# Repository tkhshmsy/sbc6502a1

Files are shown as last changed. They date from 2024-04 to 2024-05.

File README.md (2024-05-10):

# sbc6502a1
Single Board Computer with 65C02, clone of Apple I

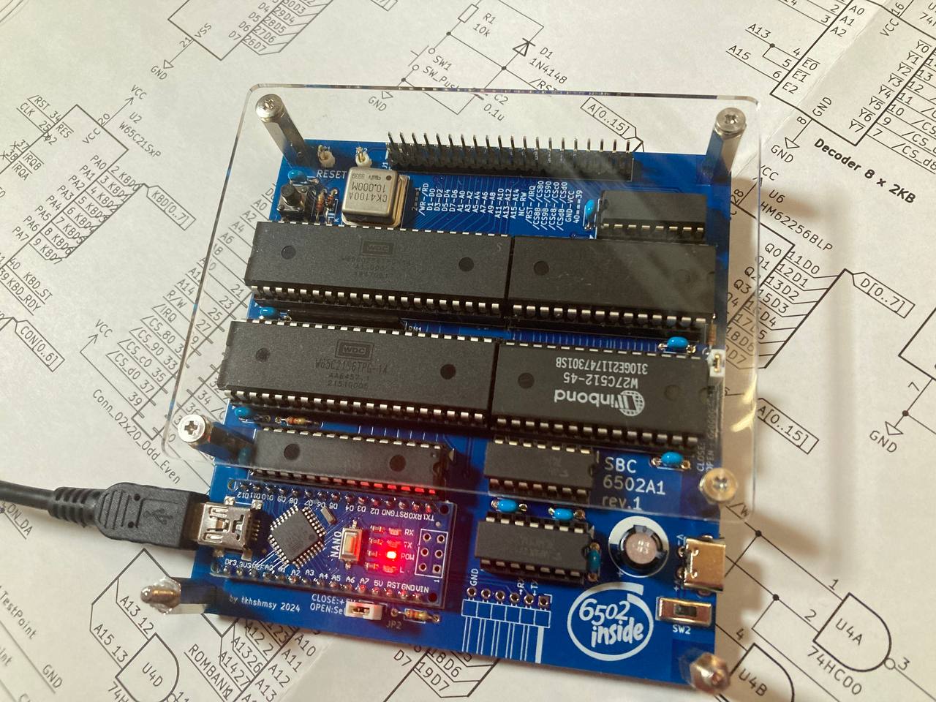
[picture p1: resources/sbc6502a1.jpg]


# Features
* Clone of Apple I.
  * similar but much ** greater ** projects are there.
    * [RC6502](https://github.com/tebl/RC6502-Apple-1-Replica) and [RC6502 Apple 1 SBC](https://github.com/tebl/RC6502-Apple-1-Replica/tree/master/RC6502%20Apple%201%20SBC)
    * [Apple 1 Mini](https://hackaday.io/project/26234/logs)
    * [L-Star](https://github.com/jacgoudsmit/L-Star/)
* Communicate with Host-PC via Serial.
  * using Arduino Nano as [PIA Communicator](https://github.com/jblang/pia_communicator)
* 32KB user RAM is available.
* ROM has 2 bank of each 8KB + 8KB.
  * it is enough for wozmon, Apple1-BASIC, OSI-BASIC and so on.
* Power supply +5VDC from Type-C or via Arduino Nano.

# PCB
## Schematics and Layout
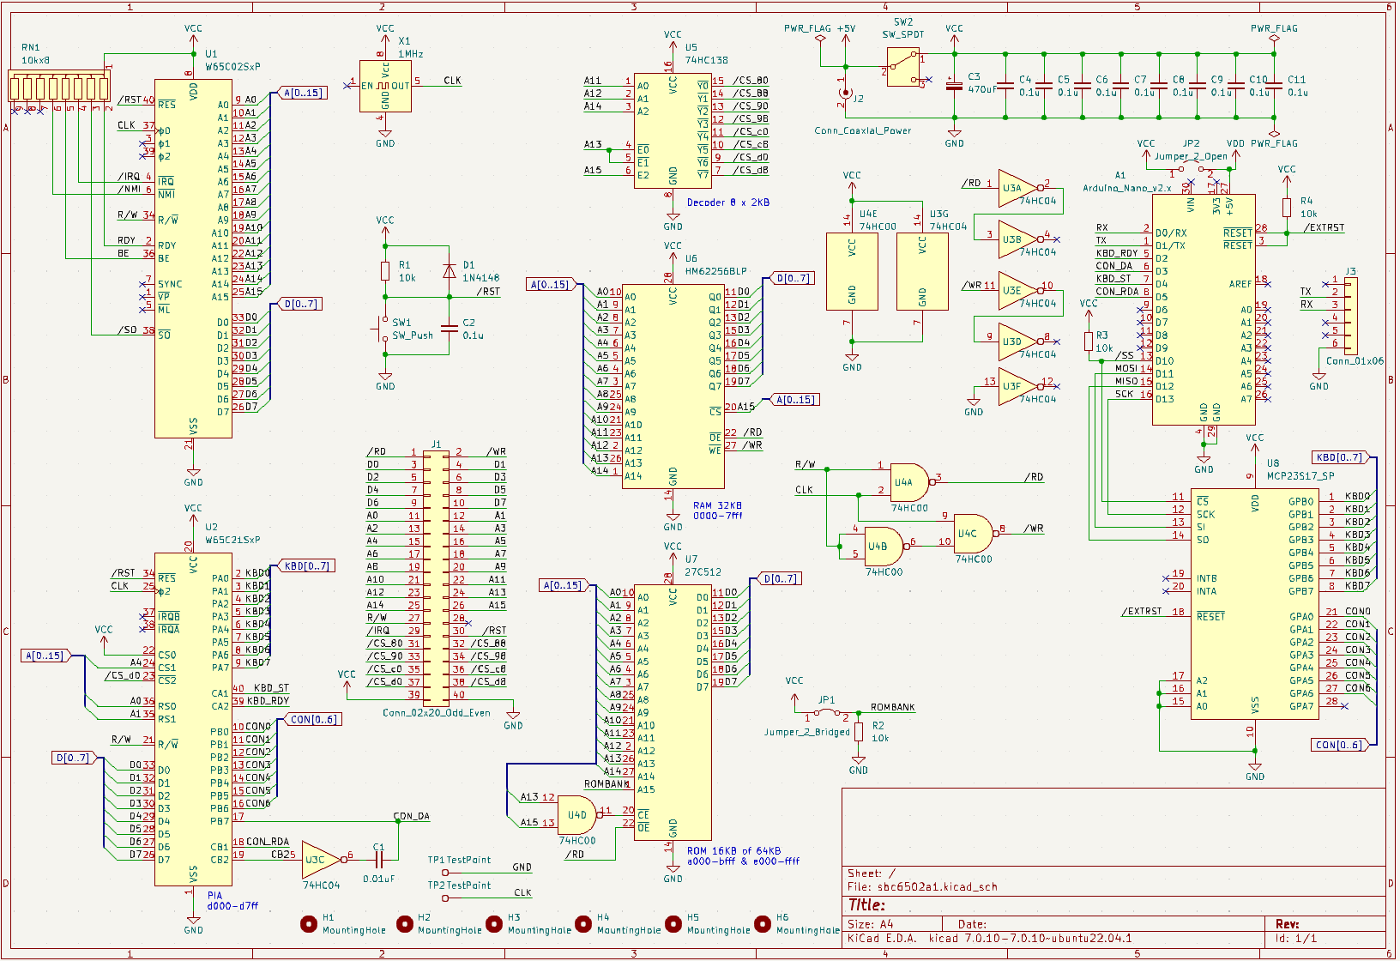
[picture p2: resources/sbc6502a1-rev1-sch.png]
sch

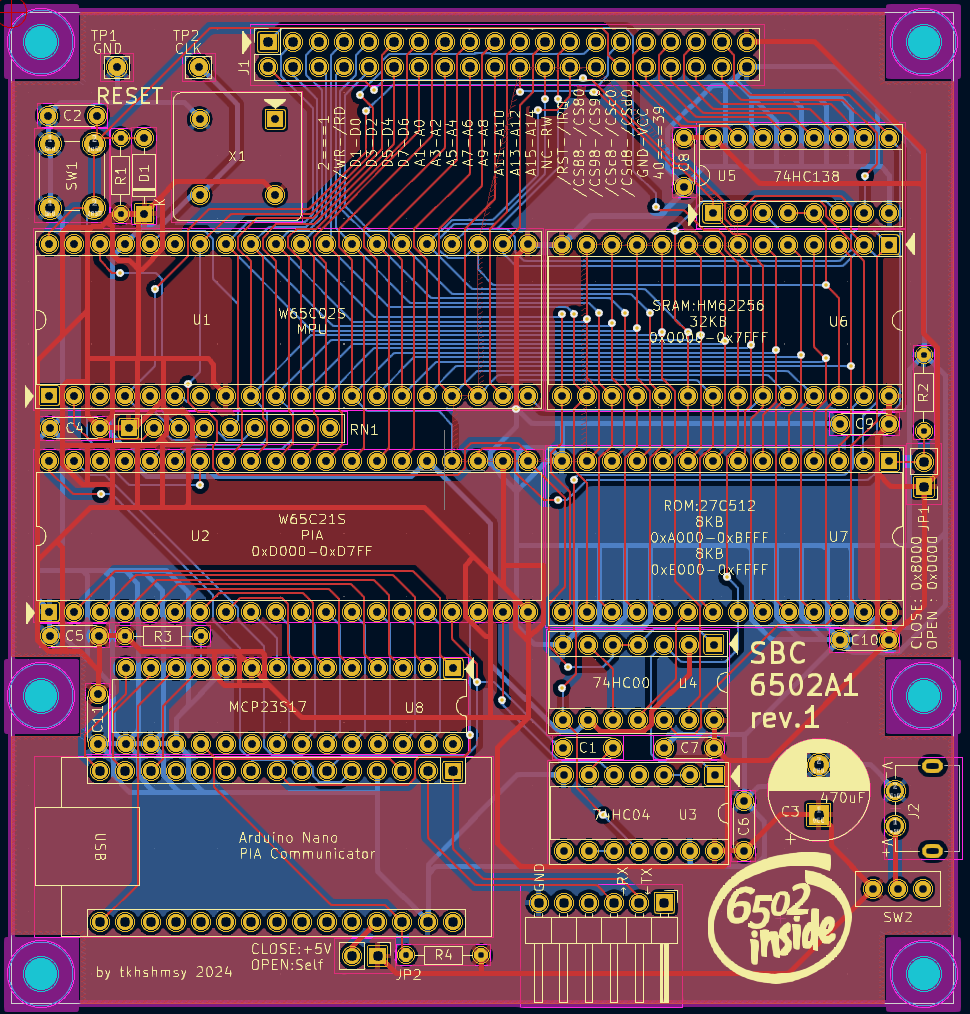
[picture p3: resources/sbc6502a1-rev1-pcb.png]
pcb


## BOM

| Ref | Name | Qty | Description | Package | Link |
| --- | ---- | --- | --- | --- | ---- |
| U1  | W65C02S | 1 | MPU 6502 | DIP40| [akizuki](https://akizukidenshi.com/catalog/g/g115324/), [mouser](https://www.mouser.jp/ProductDetail/Western-Design-Center-WDC/W65C02S6TPG-14?qs=opBjA1TV903lvWo9AEKH5w%3D%3D) |
| U2  | W65C21S | 1 | PIA 6521 | DIP40| [mouser](https://www.mouser.jp/ProductDetail/Western-Design-Center-WDC/W65C21S6TPG-14?qs=opBjA1TV9027xVsSWtzZRw%3D%3D) |
| U3  | 74HC04 | 1 | | DIP14 | [akizuki](https://akizukidenshi.com/catalog/g/g114058/) |
| U4  | 74HC00 | 1 | | DIP14 | [akizuki](https://akizukidenshi.com/catalog/g/g110856/) |
| U5  | 74HC138 | 1 | | DIP16 | [akizuki](https://akizukidenshi.com/catalog/g/g110013/) |
| U6  | 62256 | 1 | SRAM 32Kx8 | DIP28 | [mouser AS6C62256-55PCN](https://www.mouser.jp/ProductDetail/Alliance-Memory/AS6C62256-55PCN?qs=LD2UibpCYJqgbIupMJnGTQ%3D%3D), uPD43256AC-12L-13P |
| U7  | 27C512 | 1 | ROM 64Kx8 | DIP28 | W27C512-45(EEPROM), [mouser AT27C512R-45PU(OTP-EPROM)](https://www.mouser.jp/ProductDetail/Microchip-Technology/AT27C512R-45PU?qs=lURXKZrvvXf%252BnkLdiQBKDQ%3D%3D) |
| U8  | MCP23S17  | 1 | SPI/GPIO | DIP28/300mil| [akizuki](https://akizukidenshi.com/catalog/g/g110644/) |
| A1  | Arduino Nano | 1 | PIA Communicator | | [akizuki](https://akizukidenshi.com/catalog/g/g109059/), other clones |
| X1  | 1.0 MHz | 1 | Crystal OSC| DIP8 | [akizuki 1MHz](https://akizukidenshi.com/catalog/g/g117019/) |
| C1  | 0.01uF-0.1uF | 1 | | ||
| C2, C4, C5, C6, C7, C8, C9, C10, C11 | 0.1uF | 9 | | ||
| C3  | 470uF | 1 | | ||
| D1  | 1N4148 | 1 | | DO35 ||
| J1 | 2x20 Pin Header | 1 | Bus export| ||
| J2 | USB Type-C Power| 1 | Power Supply| | [akizuki](https://akizukidenshi.com/catalog/g/g116895/) |
| J3 | 1x6 Pin Header | 1 | for Serial comm| ||
| JP1, JP2 | 1x2 Pin Header | 1 | jumper select | ||
| R1, R2, R3, R4 | 10K-100K | 4 | for pullup | ||
| RN1 | 10Kx8 | 1 | for pullup | ||
| SW1 | Push Button | 1 | Reset SW| ||
| SW2 | Slide Switch | 1 | Power SW| | [akizuki](https://akizukidenshi.com/catalog/g/g115707/) |
| TP1,TP2 | Test Pin | 2 | | ||

### Note: Clock Frequency
* Original Apple1 works at 1.0 MHz
* This PCB works fine at 1.0 - 10.0 MHz
  * These clocks have been TESTED with a1basic, OSI-BASIC etc.
  * Using faster RAM and ROM, It may work even at 14 MHz, which is the limit of MPU and PIA. 

## Memory Map

### System
| Address | Size | Name | Note |
| ----- | ---- | ---- | ---- |
|0x0000 - 0x7FFF| 32KB | RAM | |
|0x8000 - 0x87FF| 2KB | (N.C.) | /CS80 |
|0x8800 - 0x8FFF| 2KB | (N.C.) | /CS88 |
|0x9000 - 0x97FF| 2KB | (N.C.) | /CS90 |
|0x9800 - 0x9FFF| 2KB | (N.C.) | /CS98 |
|0xA000 - 0xBFFF| 8KB | ROM | mapped from 0x2000 or 0xA000|
|0xC000 - 0xC7FF| 2KB | (N.C.) | /CSc0 |
|0xC800 - 0xCFFF| 2KB | (N.C.) | /CSc8 |
|0xD000 - 0xD7FF| 2KB | PIA | assigned to 0xD010 |
|0xD800 - 0xDFFF| 2KB | (N.C.) | /CSd8 |
|0xE000 - 0xFFFF| 8KB | ROM | mapped from 0x6000 or 0xE000|

### ROM (27C512 64KB)
| Address | Bank | Note |
| --- | ---- | ---- |
| 0x0000 - 0x1FFF |Bank0 (JP1 open)| no use |
| 0x2000 - 0x3FFF ||8KB, mapped to 0xA000|
| 0x4000 - 0x5FFF || no use |
| 0x6000 - 0x7FFF ||8KB, mapped to 0xE000|
| 0x8000 - 0x9FFF |Bank1 (JP1 close)| no use |
| 0xA000 - 0xBFFF ||8KB, mapped to 0xA000|
| 0xC000 - 0xDFFF || no use |
| 0xE000 - 0xFFFF ||8KB, mapped to 0xE000|

# License
* MIT
  * only for PCB
  * firmwares are NOT included.

# Author
* [tkhshmsy@gmail.com](tkhshmsy@gmail.com)

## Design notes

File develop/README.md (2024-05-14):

# sbc6502a1 How to develop

Generally, the development for 8bit MPUs is done by Assembler.  
But, C language is available for 6502.

['cc65'](https://github.com/cc65/cc65) contains C Compiler, Assembler, Linker for 6502 MPU.  

Let's custom cc65 for sbc6502a1.

## Build cc65

Here is a patch and build-script to add new target sbc6502a1.

```bash
## download, patch and build
$ cd develop/cc65
$ ./build-cc65.sh
## install
$ cd cc65
$ sudo make PREFIX=/usr/local install
```

### Detail of the patch

this patch is refer to the configurations for KIM-1.

* asminc/sbc6502a1.inc
  * common include file for ca65 assembler
    * RAMSTART is entry point of code
    * KBD, KBDRDY is come from the address of PIA
    * RESET is reset vector to start/return wozmon
    * ECHO is the routine of wozmon to send 1 character via PIA
* cfg/sbc6502a1.cfg
  * configurations for ld65 linker
    * memory map is defined by the circuit of sbc6502a1 PCB.
      * RAM is 32KB from 0x0000 to 0x7FFF
      * ROM is 8KB+8KB, but reserve 24KB from 0xA000 to 0xFFFF
* libsrc/sbc6502a1/*.s
  * library routines used from C, mainly to support wozmons' routines and PIA.
  * crt0.s
    * startup routine
    * clear BCD Math mode, prepare stack, call main() and return to wozmon.
  * ctype.s
    * set character type.
  * getkey.s
    * int getkey()
      * return character code.
  * kbhit.s
    * unsigned char kbhit()
      * return key pressed(=1) or not(=0).
      * if pressed, the result is keep until getkey() or read().
  * read.s
    * read()
      * read from KBD.
  * write.s
    * write()
      * output to DSP.
* src/ca65/main.c
* src/cc65/main.c
* src/common/target.c
* src/common/target.h
* target/Makefile
* targettest/Makefile
  * add new target sbc6502a1
  * In 'src/common/target.c', TargetMap[] requires SORTED list.

## using Assembler ca65

### Assemble and Link

For example, simple 'Hello, world!' (saved as 'hello.s')

```assembler
.include        "sbc6502a1.inc"

    .segment    "STARTUP"   ; no use but avoid ld65's warning
    .segment    "CODE"
    .org        $0300       ; start at $0300
main:
    cld                     ; clear BCD Math mode
    ldy         #0          ; Y = 0
loop:
    lda         message,y   ; A = message[Y]
    beq         done        ; if A == $00 then goto done
    jsr         ECHO        ; ECHO A, subroutine in wozmon
    iny                     ; Y++
    jmp         loop        ; goto loop
done:
    jmp         RESET       ; exit to RESET

    .segment    "RODATA"
message:
    .byte       $0D, $0A, "Hello, world!", $0D, $0A, $00

    .segment    "ONCE"      ; no use but avoid ld65's warning
    .segment    "DATA"      ; no use
```

Assemble and link,

```bash
$ export PLATFORM=sbc6502a1
## assemble
$ ca65 -t ${PLATFORM} -l hello.lst hello.s
## link
$ ld65 -t ${PLATFORM} -L /usr/local/share/cc65 -m hello.map -o hello hello.o 
```

Here, you'll get 'hello' binary.

## using C Compiler cc65

### Compile and Link

For example, simple 'Hello, world!' (saved as 'hello.c')

```c
#include <stdio.h>

int main(void)
{
  printf("Hello, world!\n");
  return;
}
```

Compile and link,

```bash
## use cl65 to compile, assemble and link.
$ export PLATFORM=sbc6502a1
$ CC65_HOME=/usr/local/share/cc65 cl65 -O -vm -m hello.map -t ${PLATFORM} hello.c

## OR you can do each step separately.
### compile to make assembly code
$ cc65 -t ${PLATFORM} -O hello.c
### assemble to make object file
$ ca65 -t ${PLATFORM} -l hello.lst hello.s
### link all
$ ld65 -t ${PLATFORM} -L /usr/local/share/cc65/lib -o hello -m hello.map hello.o ${PLATFORM}.lib
```
Here, you'll get 'hello' binary.

## Deploy into sbc6502a1
sbc6502a1 has no storage device but only serial comm.  
To deploy the program via serial, sending as IntelHex or MotorolaHex( called S-record ) formatted file is general way.  
'jmon' which is in example ROM is supported to load and run S-record file.

To make S-record file, here is 2 way. you can select one of them.
```bash
# convert hello(binary) to hello.srec(S-record)
# load address is 0x0300, and start address is 0x0300

## with srec_cat from 'srecord'
$ srec_cat hello -binary -offset 0x0300 -o hello.srec -Execution_Start_Address 0x0300

## with objcopy from 'binutils'
$ objcopy -I binary -O srec --change-addresses 0x0300 --set-start 0x0300 hello hello.srec
```

To use jmon, you need to close JP1 with example ROM image ( ROM.hex ).  
Then, boot the sbc6502a1 and open minicom on HostPC.

At boot, wozmon is running. To run jmon, type 'A000R<CR>'

```
A000R

JMON MONITOR 1.3.9 BY JEFF TRANTER
? 
```

jmon is started. Type 'J' to ready to receive,

```
LOADING
```

And send S-record file from another terminal.
If the system clock is slow, you may need to send SLOWLY.

```
$ cat hello.srec > /dev/ttyUSB0
```

After sending, automatically run the program, and exit to wozmon.

```
LOADED
Hello, World!

\
```

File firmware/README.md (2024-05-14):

# sbc6502a1 firmware

## Quick Install
ROM and PIA Communicator are required to run sbc6502a1.

### ROM

make ROM with ROM writer.

```bash
## using T48 (TL866-3G) on Ubuntu
$ sudo apt-get install build-essential pkg-config git libusb-1.0-0-dev
### get from repository
$ git clone https://gitlab.com/DavidGriffith/minipro/
$ cd minipro
$ git checkout 0.7
$ make
### install as dpkg
$ sudo apt-get install fakeroot debhelper dpkg-dev
$ fakeroot dpkg-buildpackage -b -us -uc
$ sudo apt install ../minipro_0.4-1_amd64.deb
## write the example image for W27C512
$ minipro -p W27C512@DIP28 -f ihex -w ROM.hex
```

### PIA Communicator
write 'PIA Communicator' into Arduino Nano.

* Original repository:  https://github.com/jblang/pia_communicator

```bash
### on Ubuntu
$ sudo apt install binutils-avr gcc-avr avr-libc avrdude
### get from repository
$ git submodule update -i
$ cd firmware/pia_communicator
### edit Makefile for your environment, and install
$ vim Makefile
$ make
$ make install
```

### Boot

1. install ROM and PIA Communicator into sbc6502a1 PCB.
2. choose JP1, open for Bank0 and close for Bank1.
3. close JP2.
4. connect HostPC with USB cable via ArduinoNano's USBport.
   1. so JP2 close, sbc6502a1 is powered from ArduinoNano.
   2. "wozmon" will start.
5. start minicom on HostPC.
6. Enjoy !

```bash
$ minicom -b 115200 -D /dev/ttyUSB0
```

## Contents of "ROM.hex"

Here is the example ROM image, 'ROM.hex'.

All contained programs are from other repositories.  
For details, refer to [sbc6502a1/apps/README.md](../apps/README.md).

* BANK0 (JP1 open)
  * A000 - OSI BASIC 1.0 Rev 3.2
    * 8KB, start: BD0D
    * Microsoft BASIC Interpreter with 6 digit floating point
  * E000 - a1basic
    * 4KB, start: E000
    * Apple1 Integer BASIC Interpreter
  * F000 - Krusader 1.3
    * 4KB, start: F000
    * Assembler/Disassembler monitor
  * FF00 - Krusader's minimonitor
    * start: FF00, RESET
    * modified wozmon
* BANK1 (JP1 close)
  * A000 - jmon
    * 8KB, start: A000
    * Disassembler monitor, S-Record loading supported
  * E000 - A1-Assembler
    * 4KB, start: E000
    * Symbolic Assembler
  * F000 - VTL02 C
    * 1KB, start: F000
    * VTL Interpreter
  * FF00 - wozmon
    * start: FF00, RESET

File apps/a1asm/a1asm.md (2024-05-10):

# a1asm

A1-Assembler is online symbolic assembler for 6502 based on the SB-Assembler.

For sbc6502a1, it is no need to modifiy.
* use A1AE0C.BIN for 65C02 / $e000.
  * loaded on $e000-$efff (4KB)
  * entry point is $e000

## Reference
* [SB-Project Home](https://www.sbprojects.net/index.php)
  * [SB-Assembler](https://www.sbprojects.net/sbasm/)
    * [The A1-Assembler](https://www.sbprojects.net/sbasm/a1asm.php)
      * [Download](https://www.sbprojects.net/projects/apple1/download.php)

## Example
```
%AUTO
....
%LIST
1000 PRBYTE .EQ      $FFDC
1010 ECHO   .EQ      $FFEF
1020 CR     .EQ      $8D
1030 START
1040    JSR HELLO
1050    RTS
1060 HELLO
1070    LDX #0
1080 .1
1090    LDA .3,X
1100    BPL .2
1110    JSR ECHO
1120    INX
1130    BNE .1
1140 .2
1150    ORA #%1000.0000
1160    JMP ECHO
1170 .3
1180    .AT -/HELLO WORLD/
%SBASM
$0280.$02A0
0 ERRORS
%XEC START
HELLO WORLD
%
```

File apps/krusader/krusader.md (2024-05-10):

# Krusader

Krusader is the monitor with symbolic assembler and disassembler for 6502.

For sbc6502a1, it is no need to modifiy, same as the original.  
Using [the binary](https://github.com/st3fan/krusader/tree/master/ROM) from git, 
* loaded on $f000 - $ff00
* entry point is $f000
* it includes a1basic and krusader's mini-monitor(= modified wozmon).
  * a1basic $e000 - $efff
  * mini-monitor $ff00 - $ffff

## Reference
* Ken's Rather Useless Symbolic Assembly Development Environment for the Replica 1
  * [https://github.com/st3fan/krusader](https://github.com/st3fan/krusader)
* Original ? (invalid link)
  * [http://school.anhb.uwa.edu.au/personalpages/kwessen/apple1/Krusader.htm](http://school.anhb.uwa.edu.au/personalpages/kwessen/apple1/Krusader.htm)

## Example
```
F000R

F000: A9
KRUSADER 65C02 BY KEN WESSEN 1.3
? N
000        LDA #'A'
001 LOOP   JSR $FFEF
002        CLC
003        ADC #$1
004        CMP #'Z'+1
005        BNE LOOP
006        RTS
007 
? A
0300-030C
? R $0300
ABCDEFGHIJKLMNOPQRSTUVWXYZ
? 

```

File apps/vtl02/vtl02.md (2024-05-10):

# vtl02

VTL is 'Very Tiny Language' which is a very simple language interpreter for MC6800 by Frank McCoy. Its size is only 768 bytes !

VTL02 is the implementation for 6502 by Michael T. Barry, on year 2012.

VTL02CA2 is for Apple2 of VTL02 version C, by Klaus Dormann. Also VTL02SG is the extended of it.

For sbc6502a1, modified from VTL02CA2.
* loaded on $f000 (1KB+)
* entry point is $f000
* using KBD and DSP via PIA(6521) instead of ACIA(UART, 6551).

run build-vtl02c.sh to make binary.

# Reference
* VTL02
  * [https://github.com/barrym95838/6502-Assembly](https://github.com/barrym95838/6502-Assembly)
* VTL02CA2
  * [https://github.com/Klaus2m5/VTL02](https://github.com/Klaus2m5/VTL02)

```
F000R

F000: A9
OK
1000 A=1
1010 ?=A
1020 ?=""
1030 A=A+1
1040 #=A<10*1010
#=1
1
2
3
4
5
6
7
8
9

OK
```

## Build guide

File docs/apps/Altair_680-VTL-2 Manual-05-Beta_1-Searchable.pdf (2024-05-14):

# V T L – 2

# A Very Tiny Language

## V T L – 2 for the Altair 680

### A VERY TINY LANGUAGE

For the Altair 680B and 8800 Refereces to 8800 version removed from this edition. (Later versions in C and other machines) Copyright 1976, 1977, Gary Shannon & Frank McCoy Copyright 2007, 2008, Frank McCoy

INTRODUCTION:

VTL-2 is the second Very Tiny Language developed for the Altair 680 Computer system. VTL-2 represents an enormous improvement over the earlier VTL-1 language, and incorporates some thirty additional features. In spite of these enhancements, it still requires only 768 bytes of Read-Only-Memory, and still fits into the three empty PROM sockets already on the 680 CPU board.

The statements that may be entered as input to the VTL-2 interpreter are of two types:

1. Direct statements, which have no line number, and are executed immediately after they are entered.
2. Program statements, which are used to build a program, and are not executed until the program is run. Program statements must have line-numbers identifying their location in the program.

VTL-2 is simple enough for the beginner to use easily, and yet powerful enough to serve the needs of the most advanced users. The subscripted memory reference commands, and full input-output format control, make VTL-2 a versatile language suitable for solving a wide range of computer problems.

Page 2 of 36

PRELIMINARY CONCEPTS:

Line-numbers must precede each program statement, and must be separated from that statement by a single blank space. These numbers must be in the range of 1-65535. Line-number zero is not permitted. Each line ends with a carriage-return and must be less than 73 characters long.

It is recommended that lines be numbered in steps of ten (10, 20, 30, etc.) so that new statements may be inserted if necessary.

Variables may be represented by any single alphabetic (capitals only) or special character (punctuation mark). !"#$%&&'()=-+*:;?/>.<,[] Most of these are available for the user to define as he wishes. A few of the variable names however, have been reserved for special purposes. These so-called "system variables" will be discussed in detail later.

The value assigned to a variable may be either a numeric value in the range of 0-65535, or a single ASCII character (including control-characters). Numeric and string values may be freely interchanged, in which case, the characters are equivalent to the decimal value of their ASCII code representation. Thus, it becomes possible to add 1 to the letter "A", giving as a result, the letter "B".

The arithmetic operations permitted for use in expressions are:

+ (addition)
- (subtraction)
* | (multiplication)
/ | (division)
= | (test for equality)
> | (test for greater than or equal to)
< | (test for less than)

The test operations, equal to, greater than, or equal to, and less than, all return a value of zero if the test fails, and a value of one if the test is successful.

Expressions in VTL-2 may contain any number of variables or numeric values (literal constants) connected by any of the above operation symbols. Parentheses may be used to alter the order of execution of the operations. If no parentheses are included, the operations proceed in strictly left to right order.

The value resulting from the expression must be assigned to some variable name. This is done with the equal sign. Note that the symbol has two meanings, depending on where it occurs in the expression. The expression: A=B=C means test B and C for equality; if they are equal, put a one in A; if they are unequal, put a zero in A.

Page 3 of 36

Some examples of valid arithmetic expressions would be:

Y=A*(X*X)+B*X+C | With left to right execution, this is equivalent to:
| Y=(A*X*X+B)*X+C
Y=(A*X*X)+(B*X)+C | Which is equivalent to: Y=AX^2+BX+C

Notice how the absence of parentheses around the quantity B*X in the first expression has completely altered its meaning. Keep the left to right order in mind, and when in doubt, use parentheses to control the order of evaluation.

SYSTEM VARIABLES:

In order to conserve space, and to provide a more consistent syntax, VTL-2 uses "system variables" to accomplish functions usually done with special key words in other languages. This convention is probably the single most important reason for its tiny size.

The system variable "number" or "pound sign" ‘#’ represents the line number of the line being executed. Until the statement has been completed, it will contain the current line number; so that the statement:

100 A=#

is equivalent to simply writing:

100 A=100

After completion of a line, this variable will contain the number of the next line to be executed. If nothing is done to the variable, this will be the next sequential line in the program text. If a statement changes #, however, the next line executed will be the line with the number that matches the value of #. Thus the variable # may be used to transfer control of execution to a different part of the program.

This is the VTL-2 equivalent of the BASIC "GOTO" statement. For example:

#=300 means "GOTO 300"

If the # variable should ever be set to zero by some statement, this value will be ignored, and the program will proceed as if no change had taken place. This allows us to write IF statements in VTL-2. Consider the following example:

10 X=1 | Set X equal to 1
20 #=(X=25)*50 | If X is equal to 25 then goto 50
30 X=X+1 | Add 1 to X
| Page 4 of 36

40 #=20 | Goto 20
50 ..... | Continue

Notice that the quantity (X=25) will have the value one, if it is true that X is equal to 25, and the value zero if it is false. When this logical value is multiplied times 50, the result will be either zero, or 50. If it is 50, the statement causes a "GOTO 50" to occur. If the value is zero, a "GOTO 0" which is a dummy operation, causes the next statement down (number
30) to be executed.

Taking advantage of left to right evaluation, two bytes of memory could be saved by writing:

20 #=X=25*50

Each and every time the value of # is changed by a program statement, the old-value+1 is saved in the system variable "exclamation point" ‘!’. In other words, after executing a GOTO, the line number of the line that follows the GOTO is saved so that a subroutine will know which program statement called it; and will know where to return when finished. Thus the # variable is used for both GOTO and GOSUB operations. For example:

### 10 X=1

20 #=100

### 30 X=2

40 #=100

### 50 X=3

60 #=100
100 X=X*X
110 #=! | (GOTO back where you came from)

In this example, control proceeds from line 20 to line 100. After that, line 110 causes control to return to line 30. When line 40 is executed, the subroutine at 100 will return to line 50.

The actual value stored in the ! variable is (old-line-number+1) But, VTL-2, if it does not find the exact line number it is searching for, will take the next higher existing line number. Therefore, if a program statement says "#=52" and there are lines numbered 50 and 60 with nothing in between, control passes to the next higher line number, which is line 60.

The system variable "question mark" ‘?’ represents the user's terminal. It can be either an input, or an output, depending on which side of the equal sign it appears.

Page 5 of 36

The statement "?=A" is interpreted as "PRINT A", and the statement "X=?" is interpreted as "INPUT X". Note that the "?" may be included anywhere in the expression. For example, the program:

10 ?="ENTER THREE VALUES"

### 20 A=(?+?+?)/3

30 ?="THE AVERAGE IS ";
40 ?=A

will request three inputs while executing line 20.

When typing in a reply to a request for input, the user may enter any one of three different types of data:

1. A decimal number
2. A variable name
3. Any valid VTL-2 expression

Thus, for example, the user may reply with such things as "1004" or "A+B*(9/X)". In each case, the expression is completely evaluated before the result is passed to the input statement. The only exception is that you are not allowed to respond with another question mark; as this will mess up the line pointer in the interpreter, causing it to return an improper value.

If a carriage-return, with no value, is typed in response to a request for input, the interpreter will return some undefined value. Therefore, this is not recommended.

When the question-mark is on the left side of the first equal sign, it represents a PRINT statement. When this occurs, either of two different things may be on the right side of the equal sign:

1. Any valid VTL-2 expression (as defined above)
2. A string of characters enclosed in quote marks ("")

When the expression is a numeric one, the value is computed, and printed as a left-adjusted, unsigned, decimal integer, with no leading or trailing blanks. A carriage return never follows the printing of a decimal value.

Page 6 of 36

When the expression is a quoted character string, the actual string of characters is printed, with no leading or trailing blanks. A carriage-return line-feed sequence will follow the printing of a string unless a semicolon follows the closing quote.

This omission of leading and trailing blanks allows complete control of formatting printed output. For example, the program:

10 ?=50/2
20 ?=",";
30 ?=265+3
40 ?=".";
50 ?=16

will print the line: "25,268.16" with no spaces between the pieces. This feature is most often used in floating point, and multiple precision subroutines. (See "FACTORIALS" in the sample program section.)

If at any time it is desired to have a carriage-return line-feed printed, the statement: ? ="" will accomplish this.

The system variable "per-cent" ‘%’ contains the value of the remainder of the last divide operation. This value will remain the same until the next divide operation.

The system variable "apostrophe" ‘'‘ represents a random number. This number will have an unpredictable value in the range of 0-65535. If called twice in the same line, the same value will be returned both times. The value of the variable is scrambled each time any statement is executed. Therefore, for best results it is highly recommended that at least one other computation be performed before the value is again called for. This may even be a simple dummy statement such as: Z=Z+7 For an example of this, see "DON'T LOSE YOUR AT" in the sample programs section.

In addition to decimal numeric input and output, the system variable "dollar sign" ‘$’ is used to input and output single characters. As with the question mark variable, "A=$" means "input a single ASCII character and place its numeric value in A". Similarly, "$=X" means "print the single ASCII character whose value is stored in X". For example, the program:

Page 7 of 36

### 10 A=65

20 $=A

### 30 A=A+1

40 #=A<91*20
50 ?=""

will print out, as one continuous string, all the letters of the alphabet: ABCDEFGHIJKLMNOPQRSTUVWXYZ. If you wish to find out what decimal values correspond to which characters, these can be found in your terminal operations manual, or simply computed by typing the direct statement ?=$ and then entering the character whose decimal value is to be found.

The system variable "asterisk" ‘*’ represents the memory size of your computer. For a 1k system this would be 1024. For a 32k system this would be 32*1024 or 32768. In the 680 version, this contains random data; so you should initialize it to your actual available memory on your machine.

If the user wishes to allot space for user defined machine-language-subroutines, then the variable * is set equal to the bottom of the first byte required by the user defined routine.

On compiled C versions of VTL-1 and VTL-3, the variable is preset on entry. Setting no memory available “*=0” exits the program to DOS.

The system-variable “ampersand” ‘&’ represents the next available byte of memory in the program buffer. When first calling VTL-2, or when it is desired to erase the present program, this must be initialized to the program start or the value 264 for the 680B version.. Most other versions of VTL-2, particularly the compiled ‘C’ versions, come initialized with the program empty (&=0);

&=264 | Altair 680B initialization
&=0 | Compiled ‘C’ versions (automatic)

At any given time the user may find out how much of his memory still remains unused by typing “?=*-&”. This will cause the system to respond with the number of bytes remaining. A minimum of at least three bytes are needed for any line of VTL-2. The line-numbers are saved in binary and require two bytes regardless of their decimal values. The lines “1 X=Y” and “65000 X=Y” both take up an identical 7 bytes of memory; and are examples of the normal minimum valid VTL-2 line.

Any memory past the end of a program may be used for array storage. This array storage may be used for saving numeric or string values. The array does not have a name, since there is only one, but it can be divided up into several pieces by the programmer and used for different groups of data (If the programmer has enough spare memory for the purpose). See the program “CIPHER” in the sample programs section. A subscript

Page 8 of 36 expression is identified by a colon ‘:’ and a right-parentheses. The colon marks the beginning of the expression; and the right-parentheses marks the end. Thus, for example, “:1)=0” places a zero in the first two bytes past the end of the program; and “:2+7)=A” places the value of the A variable into the 9th two-byte word past the end of the program.
Subscripts should not be allowed to be less than one (1) as this will point the subscript into the program and could cause it to be wiped out as a result. (Special programs such as the RENUMBER program make use of this feature.)

Subscript expression may be any valid VTL-2 numeric expressions. This example should clarify the use of subscript expressions.

10 I=1 | Set pointer
20 :I)=$ | Input a character to the next word
30 #=:I)=13*60 | GOTO 60 if it’s a carriage-return char.
40 I=I+1 | Point to next array word
50 #=20 | Go get another character
60 ?=”” | Print a carriage-return/line-feed
70 I=1 | Reset pointer
80 $=:I) | print Ith character
90 #=:i)=13*120 If carriage-return, then GOTO 120
100 I=I+1 | point to next character
110 #=80 | Go get next character
120 ?=”” | Print carriage-return/line-feed

The above example will read in any string of characters typed by the user, such as a sentence or paragraph, until a carriage-return is typed. It will then echo back the complete string as it was typed in.

For further examples, study the game programs which use character input and those that have arrays representing the playing board. These will be found in the Sample Program section.

Since subscripts are two-byte words, and since values as large as 65535 are allowed as subscripts, it is possible that large values in the subscript expression may “wrap around” the end of memory and reach locations within the program text itself. Therefore, there is a danger that a VTL-2 program using computed subscripts may “clobber” itself. On the other hand, this also means that a VTL-2 program may modify itself (as in the RENUMBER program) although this practice is not recommended.

The system-variable “greater-than” ‘>‘ is used to pass a value to a machine-language program. When encountered on the left side of the equal sign, the expression is evaluated, the value placed as a 16-bit integer into two registers, and control passed to the user routine. In the 6800 version, a software-interrupt (SWI) is generated, with the values passed in the A and

| Page 9 of 36

B registers. Make sure you have provided handler routines. The returned-value in the same two registers is placed in the system-variable >.

On the compiled ‘C’ versions of VTL-2 (and VTL-3) the “>” symbol is used for output to a file. The syntax is:

>=”filename”

The > variable contains the status of whether the write was successful or not.

Similarly, on the same systems, the “<” symbol is used for input from a file. Again the syntax is:

<=:”filename”

The < variable contains the status of whether the read was successful or not.

Output or input continues in each case until a Control-C character is encountered. This can either be from the console or found in the input or output. Make sure programs that output using this function include the end-character.

There is no “END” statement in VTL-2. The interpreter simply continues sequentially through the program until it runs out of lines to execute or until a statement is encountered which will try to transfer control to a line that is greater in number than any in the program.

Besides the tightly assembled versions of VTL-2 for the 8080 and 6800, there have been other versions made for the 68000 and other processors including DATA-100 terminals. Since I didn’t write the 68000 variations, I can’t tell you where to find them; only that they exist.

I have since compiled (rather huge actually) two variations of VTL to run under DOS (and that run in a DOS window under Windows). VTL2.COM and VLT-3.COM. The VTL-3 version just being a 32-bit version of VTL-2. Both are free, just for the asking. All I want there is credit for making the programs. VTL2.COM is straight-up VTL-2, with the addition of file-handling. You can enter the command from DOS:
VTL2 HURKLE.VTL

which will find the program HURKLE.VTL load it, and run it.

Write me at:

“Frank McCoy” <mccoyf@millcomm.com>

for more information; or about anything to do with VTL-2

Page 10 of 36

OPERATIONAL CHARACTERISTICS

Altair 680B version:

Switch the machine to STOP. While stopped, toggle the RESET switch. Switch to “RUN”. The monitor prompt should be typed on the terminal.

Type in:
J FC00

Once VTL-2 is in control, the message “OK” will be printed. The next step is to set your memory-size. This is done by directly entering:

*=1024 | for a 1K memory system (Basic 680B)
*=1024*33 | for a 33K system (32K expansion + 1K)
Etc.

This is unneeded on the compiled versions. They already come with maximum memory set.

Next, set the end-of-program pointer. This is done by typing:

&=264 | for a 6800 system

Again, no initialization is needed for a compiled system. &=0 being the default with no program in place.

VTL-2 is now ready to begin accepting programs and commands. If at any time it is desired to erase the program in memory, repeat the last step above. This will re-initialize the VTL-2 program space.

When a program line is entered, it will be inserted into its proper space in the program text. If the line just entered has the same line-number as a line already in the text, the old line will be replaced by the new line. If the line-number only is typed, followed immediately by a carriage-return, that line will be deleted.

While typing in program lines, VTL-2 should single-space and make no replies to lines entered. If, after typing a line, VTL-2 double-spaces down and prints, “OK”, that indicates that there was not enough memory available to insert the new line just typed.

The user may check to see how much memory remains for program entry at any time by typing the direct statement:

?=*-&

| Page 11 of 36

The system will then respond with the number of bytes still available for program entry.

While typing in a line, the back-arrow key (Shift-0 on some terminals, Underline on others) will cause the last character typed to be deleted from the input-buffer. The character will still appear on the screen, terminal, or printout; but will no longer be in memory. Thus the line: “A=B*C__+N” goes in as “A=B+N”, where the “*C” was deleted by the two back-arrow (or underline) characters. This precludes the use of the underscore character as a variable. On the compiled ‘C’ versions, the backspace-character also works.

At any time before hitting Return, the entire line may be erased by typing the At-sign character ‘@’ (Shift-P or “Cancel” on some terminals.)

Typing the single character zero ‘0’ followed by a carriage-return causes VTL-2 to print out a complete listing of the program.

While printing is taking place, whether as a program listing or as output from a program, the operation can be cancelled and control returned to the operator by pressing Control-C. When this is done, VTL-2 completes its current print statement, and then prints “OK” to acknowledge the interruption.

In addition to this, any other key (preferably a non-printing control-character such as Control-A) may be pressed. This will cause VTL-2 to temporarily suspend operation and wait for another key to be pressed. (Again, preferably another non-printing character.)

This feature allows users with video terminals to list their programs a section at a time; hitting Control-A to stop the listing; and hitting it again to resume listing.

Note that these characters also affect printing being done by a program. You may temporarily halt your program with a Control-A, and start it up again with another Control-A. These keys only work during printing which uses the question-mark ‘?’ system-variable. String printing with the dollar-sign ‘$’ variable will NOT interrupt in this manner. This allows the user the option of making his program interruptible or non-interruptible.

Should an uninterruptible program become “locked up” in a loop, the only way out is with the front-panel reset, as described above when starting. You can then jump to VTl-2 in the same manner you did when starting; just don’t re-initialize the program-pointer, and your program should still be in memory for you to edit or run again.

To run a program once entered, the user simply types the direct command:

#=1

This causes VTL-2 to find the lowest numbered line and start executing there. If it is desired to begin execution at some other line, say line 1000, simply type:

Page 12 of 36

#=1000

or whatever line is desired to start at.

Comments may be inserted on any line by preceding them with a right-parentheses ‘)’ character. This symbol must follow the expression on the line immediately, with no blanks in between. This causes VTL-2 to stop evaluating the line and go on to the next line. If a line is to contain only a comment, then the first character on the line should be a right-parentheses. Examples of commented lines:

100 A=2) | Initialize variable
110 ) | Just a comment alone.

There are no error-messages in VTL-2. If an expression is wrong, the results of evaluating that expression will also be wrong. ALL expressions, even if improperly formed, WILL be evaluated! In other words: VTL-2 assumes that you know what you are doing; and will do its best to execute any statement that you give it. This leaves WIDE latitude for trying various program “tricks”; but also leaves the complete responsibility for verifying program accuracy with the programmer. Thus you will have ample opportunity to “shoot yourself in the foot” if not careful.

For those who would like to experiment with VTL-2 on a DOS based machine, I have copies of VTL2.COM and VTL3.COM that I distribute freely. VTL-3 being a 32-bit version of VTL-2,

Simply send me an email at:

“Frank McCoy” <mccoyf@millcomm.com>

asking for a copy, and I’ll send you one. The only limit I place on the usage is recognition of authorship.

I also appreciate hearing of any interesting VTL2 programs other people have created. Listings *much* appreciated!

(Note from Grant, I would also appreciate hearing about VTL-2 programs! Send me an e-mail at grant@stockly.com or share your program on the http://www.stockly.com forums.)

Page 13 of 36

### Sample of Programming

(680B version)

When starting: A. Lift the Run/Halt-switch.
B. Turn the computer on.
C. Lift the Reset-switch
D. Turn the Run/Halt-switch to Run
E. The monitor should reply with a period (.)
F. Type in J FC00
G. VTL-2 should reply with “OK”
OK | VTL-2 prompt
*=1024 | Set memory-size to 1024 bytes
OK | VTL-2 prompt
&=264 | Reset program pointer
OK | VTL-2 prompt
10 A=0 | Set A equal to zero
20 B=1 | Set B equal to one
30 ?=A | Print the factorial number
40 “=”! = “; | Print “Factorial equals”
50 ?=B | Print the value of the factorial
60 ?=”” | Print a carriage-return/line-feed
70 A=A+1 | Increment factorial number
80 B=B*A | Calculate next by multiplication
90 #=A<9*30 | If less than !9 then GOTO step 30
#=10 | Execute program

0! = 1 | (Program Output)
1! = 1
2! = 2
3! = 6
4! = 24
5! = 120
6! = 720
8! = 40320
OK | VTL-2 prompt saying it’s done.

Page 14 of 36

### List of new features of VTL-2 Compared to VTL-1

#1 | 11 more variables

#2 | 1 array

#3 | Computed return-address

#4 | End-of-program pointer

#5 | End-of-memory pointer

#6 | Random number generator

#7 | Single character string input

#8 | Single character string output

#9 | Machine-language subroutines

#10 Computed line inputs

#11 Computed array

#12 Faster operation

#13 Input/output compatibility on LIST #14 Faster line insertion

#15 No double carriage-return on line inputs

#16 “OK” prompt

#17 No prompt on line-insertion

#18 Nulls and control-characters equal or less than carriage-return are not inserted into lines #19 Control-C stops execution when printing

#20 Any key pressed suspend operation when printing

| Any key pressed resumes operation when printing
#21 All interrupt vectors are preserved

#22 On initialization, setting the line-number equal to zero is no longer needed #23 Multiple operations are allowed on a value on a line

#24 Single and multiple parentheses are allowed

#25 Print statements may be with or without a following carriage-return/line-feed #26 No leading or trailing spaces are added to a printed number

#27 # stands for present line number, not present line-number plus one

#28 More understandable system variables. EI: # stands for line-number

#29 33 more bytes are allotted for program space

#30 Programs takes up 10% less space in memory

#31 Up to 72 characters are allowed per line

Page 15 of 36

### List of Features

Variables:

Variable: | Meaning
A-Z | Common Variables
| Use freely for storing values

System Variables:

! | Return-Address
| Points to line# after the last #= statement
“ | Pointer for literal print statements
# | Current line-number

$ | Single-character input or output
% | Remainder after last divide operation
& | Points to last byte of program
’ | Random number
( | Sets start of parenthesized expression
) | End:
| Sets end of line
| Sets end of parenthesized expression
| Sets end of array description
| Used also for REMARK statements
* | Points to end of memory
> | Machine-language subroutine (680 or 8800)
| Output to disk-file (Compiled C versions)
< | Input from disk-file (Compiled C versions)
? | Print statement when left of equal-sign
| Input statement when right of equal-sign
: | Defines start of array description
; | When following a literal print-statement,
| says do not print carriage-return/line-feed
.-=;+,/^[] | May be used as standard variables;
| But use not recommended for legibility reasons

Page 16 of 36

Operators:

+ | Add to previous value
- Subtract from previous value
* | Multiply times previous value
/ | Divide previous value by
= | Is previous value equal to (Yes = 1, No = 0)
< | Is previous value less than (Yes = 1, No = 0)
> | Is previous value equal-to or greater than
| (Yes = 1, No = 0)
The default operator is the less-than test, if symbol for operator is unrecognized.

Page 17 of 36

### Control-Code Cross-Reference For some common video terminals

All numeric values in decimal X and Y are decimal values

Usage | Info-Term | SWTP-TVT VT-100/ANSI.SYS
Home-Up | 18 | 19 | <Esc>[H
Erase-Screen | 28 | 22 | <Esc>[J
Goto X,Y | | | <Esc>[X;Y]H
Form-Feed | 12 | 12 | 12
(Next page on TVT.)
Carriage-Return | 13 | 13 | 13
Back-Space | 8 | 8 | 8
Line-Feed | 10 | 10 | 10
Back-Cursor | 19 | 18 | <Esc>[D
Up-Cursor | | 21 | <Esc>[A
Down-Cursor | 10 | 10 | <Esc>[B

These codes can usually be translated one-for-one, from one program to another. For example, where you see:

100 $=22 | For the SWTP TVT, You’d enter:
100 $=27 | For a VT-100 or computer running ANSI.SYS
101 ?=”[J”;

The remainder of this manual contains sample programs. You do not need to retype all of these programs, they can be downloaded from the forums at http://www.stockly.com. Programs may be “pasted” into the Altair 680 using a serial terminal program like HyperTerm or TeraTerm. See the forums for more information!

Page 18 of 36

### HURKLE

100 ?=""
110 ?="A HURKLE IS HIDING ON A" 120 ?="10 BY 10 GRID. HOMEBASE" 130 ?="ON THE GRID IS POINT 00" 140 ?="AND A GRIDPOINT IS ANY"
150 ?="PAIR OF WHOLE NUMBERS"
160 ?="TRY TO GUESS THE HURKLE'S" 170 ?="GRIDPOINT. YOU GET 5 GUESSES" 180 ?=""
190 R='/100*0+%
200 A=R/10
210 B=%
220 K=1
230 ?="GUESS #";
240 ?=K
250 ?=" ?";
260 X=?/10
270 Y=%
280 ?=""
290 #=X*10+Y=R*540
300 K=K+1
310 #=K=6*440
320 ?="GO ";
330 #=Y=B*370+(Y<B*360)
340 ?="SOUTH";
350 #=370
360 ?="NORTH";
370 #=X=A*410+(X<A*400)
380 ?="WEST";
390 #=410
400 ?="EAST";
410 ?=""
420 ?=""
430 #=230
440 ?=""
450 ?="SORRY THAT'S 5 GUESSES" 460 ?="THE HURKLE IS AT "; 470 ?=A
480 ?=B
490 ?=""
500 ?=""
510 ?="LETS PLAY AGAIN."
520 ?="HURKLE IS HIDING"
530 #=180
540 ?="YOU FOUND HIM IN "; 550 ?=K
560 ?=" GUESSES"
570 #=490

Page 19 of 36

### TIME OF DAY DIGITAL CLOCK

FOR 300 BUAD TERMINALS: FOR 110 BAUD TERMINALS:

10 ?="HOUR ?"; | 10 ?="HOUR ?";
20 H=? | 20 H=?
30 ?="MINUTE ?"; | 30 ?="MINUTE ?";
40 M=? | 40 M=?
50 ?="SECOND ?"; | 50 ?="SECOND ?";
60 S=? | 60 S=?
70 ?="READY" | 70 ?="READY"
80 A=$ | 80 A=$
90 S=S+1 | 90 S=S+1
100 M=S/60+M | 100 M=S/60+M
110 S=% | 110 S=%
120 H=M/60+H | 120 H=M/60+H
130 M=% | 130 M=%
140 H=H/24*0+% | 140 H=H/24*0+%
150 ?="TIME: "; | 150 ?=H/10
160 ?=H/10 | 160 ?=%
170 ?=% | 170 ?=":";
180 ?=":"; | 180 ?=M/10
190 ?=M/10 | 190 ?=%
200 ?=% | 200 ?=":";
210 ?=":"; | 210 ?=S/10
220 ?=S/10 | 220 ?=%
230 ?=% | 230 $=13
240 $=13 | 240 A=B
250 A=B | 250 A=B
260 T=31 | 260 A=B
270 T=T-1 | 270 A=B+B
280 #=T=0*90 | 280 T=14
290 #=270 | 290 T=T-1
| 300 #=T=0*90
| 310 #=290

Page 20 of 36

FACTORIALS

CALCULATES FACTORIALS UNTIL IT RUNS OUT OF MEMORY FOR IK OF MEMORY THIS IS ABOUT 208!

### 10 A=1 20 L=2

30 :1)=1

### 40 I=2

50 :I)=0

### 60 I=I+1

70 #=L>I*50
80 ?=""
90 ?=""
100 ?=A
110 ?="! ="
120 ?=""
130 I=L+1
140 I=I-1
150 #=:I)=0*140
160 ?=:I)
170 I=I-1
180 #=I=0*220
190 ?=:I)/10
200 ?=%
210 #=170
220 A=A+1
230 I=1
240 C=0
250 X=:I)
260 :I)=A*X
270 #=:I)<X*320
280 :I)=:I)+C
290 C=:I)/100
300 :I)=%
310 I=I+1
320 #=L>I*250
330 #=C=0*80
340 L=L+1
350 #=*-&/2<L*380
360 :I)=C
370 #=290

Page 21 of 36

### WEEKDAY

10 #=440 | 470 :4)=6
20 ?="DAY OF THE WEEK" | 480 :5)=1
30 ?="" | 490 :6)=4
40 ?="MONTH? "; | 500 :7)=6
50 M=? | 510 :8)=2
60 #=M>13*40 | 520 :9)=5
70 #=M=0*40 | 530 :10)=0
80 ?=DAY OF MONTH? "; | 540 :11)=3
90 D=? | 550 :12)=5
100 ?="YEAR? " | 560 #=20
110 Y=?
120 #=Y>1800*230
130 #=Y<100*150
140 #=70
150 ?=""
160 ?="IS THAT 19";
170 ?=Y
180 ?="? ";
190 K=$
200 #=K=89=0*70
210 ?="ES"
220 Y=Y+1900
230 C=Y/100
240 Y=%
250 #=Y/4*0+%=0*280
260 :1)=6
270 :2)=2
280 W=Y/4+Y+D+:M)+(2*(C=18))/7*0+% 290 #=300+(20*W)
300 ?="SUN";
310 #=430
320 ?="MON";
330 #=430
340 ?="TUES";
350 #=430
360 ?="WEDNES";
370 #=340
380 ?="THURS";
390 #=430
400 ?="FRI";
410 #=430
420 ?="SATUR";
430 ?="DAY"
440 :1)=0
450 :2)=3
460 :3)=3

Page 22 of 36

### STARSHOOTER

10 I=0 | | 290 #=:I)=95=0*250
20 I=I+1 | | 300 I=I-1
30 :I)=46 | | 310 #=260
40 #=I<41*20 | 320 A=:43)-64
50 :25)=42 | | 330 ?=""
60 I=8 | | 340 #=A>6*230
70 J=1 | | 350 B=:44)-48
80 $=I-1/7+64 | 360 #=B>6*230
90 ?=" - "; | 370 S=A*7+1+B
100 S=I+J | | 380 ?=""
110 $=:S) | | 390 #=:S)=42*420
120 J=J+1 | | 400 ?="THAT'S NOT A STAR!"
130 #=J=6*160 | 410 #=230
140 ?=" "; | 420 :S)=46
150 #=100 | | 430 C=S-7
160 I=I+7 | | 440 #=520
170 ?="" | | 450 C=S-1
180 ?="" | | 460 #=520
190 #=I<43*70 | 470 C=S+1
200 ?="" | | 480 #=520
210 ?=" | 1 2 3 4 5" | 490 C=S+7
220 ?="" | | 500 #=520
230 ?="YOUR MOVE --"; | 510 #=60
240 I=42 | | 520 ^=!
250 I=I+1 | | 530 #=:C)=42*560
260 :I)=$ | | 540 :C)=42
270 #=:I)=13*320 | 550 #=^
280 #=:I)=3*580 | 560 :C)=46
| | 570 #=^
Object of the game is to change this: | To this:
A - | | A - * * * * *
B - | | B - * . . . *
C - . . * . . | C - * . . . *
D - | | D - * . . . *
E - | | E - * * * * *
1 2 3 4 5 | 1 2 3 4 5

Page 23 of 36

### MEMORY TEST

10 A=0 | 410 L=L+1
20 ?="MEMORY SIZE? "; | 420 #=L<8*360
30 B=? | 430 ?="BIT IN ERROR IS #";
40 A=A+257 | 440 ?=L
50 C=A | 450 ?=""

### 60 I=0 70 I=I+1

80 :I)=C

### 90 C=C+769

95 ?="";
100 #=I*2+&<B*70
110 C=A
120 I=0
130 I=I+1
140 D=:I)
145 #=D=C=0*170
150 C=C+769
155 ?="";
160 #=130
170 E=C/256
180 F=%
190 G=D/256
200 H=%
210 J=E=G
220 P=I*2+&+J
230 #=P<B*300
240 ?="TEST # ";
250 ?=A/256
260 ?=" COMPLETE"
270 #=A<65535*40
280 ?="DONE"
290 #=999
300 ?="ERROR AT BYTE #";
305 ?=P
310 ?=""
320 #=J*342
330 F=E
340 H=G
342 ?=" TEST BYTE WAS ";
344 ?=F
345 ?=""
346 ?="ERROR BYTE WAS ";
348 ?=H
349 ?=""
350 L=0
360 F=F/2
370 M=%
380 H=H/2
390 N=%
400 #=M=N=0*430

Page 24 of 36

### FACTORS

Calculates factors of a number

10 ?="NUMBER? ";

### 20 N=? 30 X=N

40 $=27
45 ?="[2J";
50 ?=N
60 ?=" IS ";
70 #=N/2*0+%=0*140

### 80 D=3 90 Q=N/D

100 #=%=0*160
110 #=D>Q*300
120 D=D+2
130 #=90
140 ?="EVEN."
150 #=10
160 ?=""
170 ?=D
180 N=Q
190 Q=N/D
200 #=%=0*220
210 #=120
220 ?="^";
230 P=1
240 N=Q
250 Q=N/D
260 P=P+1
270 #=%=0*240
280 ?=P
290 #=120
300 #=N=1*340
310 #=N=X*390
320 ?=""
330 ?=N
340 ?=""
350 ?="DONE"
370 ?=""
380 #=10
390 ?="PRIME."
400 ?=""
410 #=340

Page 25 of 36

### DON'T LOSE YOUR AT!

BY
Ed Verner
Adapted to VTL-2 BY Gary Shannon (A game similar to "BAGLES")

The object of the game is to guess the secret number picked by the computer. The number has three digits, no zeroes, and no digit is repeated. After you type in your guess, the computer will print an “IT” for every correct digit in the wrong position, and an “AT” for every correct digit in the right position. You win when you get three “AT”s. Each time that you guess incorrectly, you lose 5% of the points you have left

10 T=0 | 310 #=C=X*S
20 L=0 | 320 #=C=Y*S
30 ?="DON'T LOSE YOUR 'AT'" | 330 K=0
40 X='/9*0+%+1 | 340 S=620
50 Y='/9*0+%+1 | 350 #=A=X*S
60 #=X=Y*40 | 360 #=B=Y*S
70 Z='/9*0+%+1 | 370 #=C=Z*S
80 #=X=Z*40 | 380 #=K<3*580
90 #=Y=Z*40 | 390 ?=""
100 ?="I'VE GOT A NUMBER." | 400 ?="YOU WIN ";
105 L=L+1 | 410 ?=P/100
110 P=10000 | 420 ?=".";
120 ?="" | 430 ?=%/10
130 ?="YOU HAVE "; | 440 ?=%
140 ?=P/100 | 450 ?=" POINTS FOR A TOTAL OF ";
150 ?="."; | 460 T=T+P
160 ?=%/10 | 490 ?=T/100
170 ?=% | 500 ?=".";
180 ?=" POINTS LEFT" | 510 ?=%/10
190 ?="" | 520 ?=%
200 ?="WHAT'S YOUR GUESS? -- "; 540 ?=" POINTS IN ";
210 G=? | 550 ?=L
220 A=G/100 | 560 ?=" GAMES."
230 B=%/10 | 570 #=30
240 C=% | 580 P=P/20*19
260 S=600 | 590 #=120
270 #=A=Y*S | 600 ?="IT ";
280 #=A=Z*S | 610 #=!
290 #=B=X*S | 620 ?="AT ";
300 #=B=Z*S | 630 K=K+1
| 640 #=!

****************************** HAVE FUN! ***************************

Page 26 of 36

### CRAPS!

10 T=100 | 310 A=$
20 $=22 | 320 #=500
30 ?="CRAPS!" | 330 #=R=7*390
40 ?="" | 340 #=R=P*360
50 ?="HOW MUCH DO YOU BET? - "; | 350 #=300
60 B=? | 360 ?="YOU WIN"
70 #=B=0*90 | 370 T=T+B
80 ?="GOOD LUCK!" | 380 #=120
90 #=B=0*480 | 390 T=T-B
100 #=T>B*160 | 400 ?="YOU LOSE"
110 ?="TOO MUCH!" | 410 #=T=0*430
120 ?="YOU HAVE $"; | 420 #=120
130 ?=T | 430 ?="YOU ARE BUSTED!"
140 ?=" LEFT." | 440 ?="MOVE OVER AND LET THE NEXT"
150 #=40 | 450 ?="SUCKER TRY."
160 ?="" | 460 ?=""
170 ?="ROLL-"; | 470 #=10
180 A=? | 480 ?="BE SERIOUS"
190 $=22 | 490 #=40
200 ?="FIRST ROLL: "; | 500 R='/6*0+%+1
210 #=500 | 510 ?=R
220 #=R=7*360 | 520 X=X+11213
230 #=R=11*360 | 530 ?=" AND ";
240 #=R<4*390 | 540 S='/6*0+%+1
250 #=R=12*390 | 550 X=X*56001
260 ?="" | 560 ?=S
270 ?=R | 570 ?=" (";
280 ?=" IS YOUR POINT" | 580 R=R+S
290 P=R | 590 ?=R
300 ?="ROLL-"; | 600 ?=")"
| 610 #=!

Page 27 of 36

### CIPHER GAME

10 I=0 | 260 :I)=:T)
20 I=I+1 | 270 I=I+1
30 :I)=I+64 | 280 #=:I)>14*240
40 #=I<26*20 | 290 ?=""
50 I=1 | 300 ?="CODE:"
60 ?="" | 310 ?=""
70 M='/26*0+%+1 | 320 I=27
80 H=:M) | 330 $=:I)
90 :M)=:I) | 340 #=:I)=13*370
100 :I)=H | 350 I=I+1
110 I=I+1 | 360 #=330
120 #=I<27*70 | 370 ?=""
130 ?="TEXT?" | 380 ?="SWITCH? - ";
140 ?="" | 390 A=$
150 I=27 | 400 B=$
160 :I)=$ | 410 #=B=64*370
170 #=:I)=13*220 | 420 I=27
180 #=:I)=95=0*200 430 #=:I)=A*490
190 I=I-2 | 440 #=:I)=B=0*460
200 I=I+1 | 450 :I)=A
210 #=160 | 460 I=I+1
220 ?="" | 470 #=:I)=13*290
230 I=27 | 480 #=430
240 #=:I)<64*270 | 490 :I)=B
250 T=:I)-64 | 500 #=460

Page 28 of 36

### PHRASE SORT

10 $=22

### 20 I=0 30 I=I+1

40 :I)=$

### 50 L=:I)=95*2 60 I=I-L

70 #=:I)>14*30
80 ?=""

### 90 I=1

100 K=I
110 J=K
120 #=:K)=32*160
130 #=:J)=32*150
140 #=:K)>:J)*160
150 J=K
160 K=K+1
170 #=:K)>14*120
180 H=:I)
190 :I)=:J)
200 :J)=H
210 I=I+1
220 #=:I)>14*100
230 I=0
240 I=I+1
250 $=:I)
260 #=:I)>14*240
270 ?=""

Page 29 of 36

### LUNAR LANDER

10 $=26 | 494 W=L
20 ?=" | LUNAR LANDER" | 495 L=X/L+L/2
30 )BY SU-MING WU | 496 #=L<W*494
40 )MAR-VISTA CA. | 497 L=L/2
50 )MAY 1977 | 500 #=L<2*470
55 )CORRECTED BY FRANK MCCOY | 510 ?="YOU HIT THE GROUND WITH A VELOCITY OF ";
56 )JUNE 6 1977 | 520 ?=L
60 ?="" | 530 ?=" FEET PER SECOND"
90 F=120 | 540 #=L>10*580
110 V=50 | 550 #=L>5*562
120 D=500 | 555 ?="A VERY GOOD LANDING"
130 ?="FUEL SPEED DISTANCE BURN" | 560 #=600
140 T=F | 562 #=L>8*570
141 #=410 | 563 ?="A FAIR LANDING, BUT YOU DAMAGED"
142 ?=F | 564 ?="PART OF YOUR LANDING GEAR"
150 ?=" "; | 565 #=600
151 T=V<10000*V+(V>10000*(0-V))
152 #=410
153 $=T=V*32+(T<V*45)
154 ?=T
160 T=D
161 ?=" | "; | 570 ?="A POOR LANDING---YOU'LL PROBABLY BE STRANDED HERE"
162 #=410 | 575 ?="FOR THE REST OF YOUR SHORT LIFE"
163 ?=D | 576 #=600
170 ?=" ? "; | 580 ?="NO SURVIVERS-----REST IN PEACE"
220 B=? | 600 ?=""
230 B=B<F*B+(B>F*F) | 610 ?=""
240 F=F-B | 620 ?=""
250 #=B<5*280 | 630 ?=""
260 Z=B-5/2 | 640 ?="DO YOU WANT TO PLAY AGAIN? ";
270 #=290 | 650 A=$
280 Z=0-(0-B+5/2) | 660 #=A=89*10
290 #=Z+D-V=0+(V-B+5=0)=2*470 | 670 #=A=78=0*630
291 #=Z+D-V-1>10000*490 | 680 ?="O";
293 D=Z+D-V
294 V=V-B+5
300 B=0
305 #=F=0*490
310 #=140
410 #=T>1000*!
420 ?=" ";
430 #=T>100*!
440 ?=" ";
450 #=T>10*!
460 ?=" ";
465 #=!
470 ?="PERFECT LANDING!"
480 #=600
490 L=V*V+(5-B*D*2)
491 #=L=0*499
493 X=L*4

Page 30 of 36

### LIFE FAST VERSION

10 #=370

### 20 S=Y<F*Y+(Y=0*E)+(Y=F)-1*O+(X<Q*X+(X=0*O)+(X=Q))

25 :S)=:S)+2
30 X=X+1-(J<X*3)+(J-1=X*(Y=I)) | 490 #=J>I*470
40 Y=J-1=X+Y | 495 #=631
50 #=I+1>Y*20 | 500 I=1
70 #=90 | 510 ?=""
80 #=:I-1*O+J)/2*0+%*20 | 520 J=1
90 J=J+1-(O=J*O) | 530 #=I>10*550
100 I=J=1+I | 540 ?=" ";
110 ?=""; | 550 ?=I
120 X=J-1 | 560 ?=" ";
130 Y=I-1 | 570 L=$
140 #=I<F*80 | 580 :I-1*O+J)=L=32+(L=13)+(L=95)+(L=64)=0*6
150 I=1 | 590 J=J+1-(L=95*2)
160 J=1 | 600 #=L=13*620+(L=64*510)
180 ?="" | 610 #=J<Q*570
190 P=0 | 620 I=I+1
200 K=I-1*O+J | 625 #=I<F*510
210 :K)=:K)<5+(:K)>8)=0 | 626 #=631
220 P=P+:K) | 627 #=150
230 $=:K)*10+32 | 631 $=22
240 J=J+1-(J=O*O) | 632 $=18
250 #=1<J*200 | 633 $=32
260 ?="" | 634 $=18
270 I=I+1 | 635 $=22
280 #=I<F*200 | 636 $=18
290 ?="GEN = "; | 637 $=32
300 ?=G | 638 $=18
310 G=G+1 | 640 #=!
320 ?=" | POP = ";
330 ?=P
340 I=1
350 J=1
360 #=0<P*110+(P=0*650)
370 I=1
380 G=0
390 ?="SIZE? ";
400 O=?
410 Q=O+1
420 ?="BY? ";
430 E=?
440 F=E+1
450 J=O*E+2
460 #=J*2+&>**390
470 :I)=0
480 I=I+1

This program takes at least 2K to operate properly.
This version was written for the SWTP TVT; but will run on any normal terminal. For best results (on the TVT) try for a 31 by 15 matrix.

Page 31 of 36

### TIC-TAC-TOE

This version for Dec VT-100 Or compatibles (ANSI.SYS)

1000 Q=0
1010 H=0
1020 J=0
1030 I=0
1035 $=27
1037 ?="[J";
1040 U=0
1050 S=1
1054 ?=""
1056 ?=""
1060 I=I+1
1070 :I)=I+48
1080 #=I<9*1060
1090 #=1680
1100 $=27
1101 ?="[H";
1110 ?=""
1120 ?=" YOUR MOVE - ";
1130 U=1
1140 M=$-48
1150 #=3-48=M*2040
1160 ?=""
1170 #=M=0*1030
1180 #=9<M*1211
1190 #=:M)<65*1240
1191 $=27
1192 ?="[H";
1200 ?=" SOMEBODY ALREADY THERE" 1210 #=1120
1211 $=27
1212 ?="[H";
1220 ?=" | ILLEGAL MOVE! | "
1230 #=1120
1240 :M)=88
1250 #=1680
1260 X=1
1270 L=0
1280 K=0
1290 N=1
1300 A=N
1310 B=X+N
1320 C=2*X+N
1330 #=:A)=:B)+(:A)=:C))=2*1880 1340 #=:A)=:B)+(:C)<65)=2*1410 1350 D=A
1360 A=B
1370 B=C
1380 C=D
1390 #=A=N*1440
1400 #=1340
1410 #=K>1*(:L)=79)*1440
1420 L=A
1430 K=C
1440 #=X=4+(2*X+N=9+(X=2))*30+#
| | Page 32 of 36

1450 N=X=1*2+1+N
1460 #=1300
1470 X=X+1
1480 N=X=2*2+1
1490 #=1300
1500 #=K>1*1620
1510 I=0
1520 P=0
1530 I=I+1
1540 P=:I)>65+P
1550 #=I<9*1530
1560 #=P=9*1950
1570 K=M
1575 X=0
1580 K=:5)>65*(K+S/2*0+%+('/16384*2+1)+K/10*0+%/9*0+%+1) 1590 K=:5)<65*5+K
1600 X=X+1
1605 S=X>9+S
1610 #=:K)>65*1580
1620 :K)=79
1625 S=:5)=79*M+S/2*0+%
1630 #=L>1*(:L)=79)*1910
1640 !=1100
1650 $=27
1655 ?="[H";
1660 ?=" | MY MOVE | - ";
1670 ?=K
1675 ?=" | "
1677 ?=""
1680 ?=""
1690 ?=""
1700 R=!
1710 I=7
1720 ?=" | | | |"
1725 ?=" | ";
1730 ?=" ";
1740 #=U*1770
1750 $=:I)
1760 #=1780
1770 $=:I)<65*32+(:I)>65*:I)) 1780 P=:I)>65+P
1790 I=I+1
1800 #=I/3*0+%=1*1830
1810 ?=" |";
1820 #=1730
1830 ?=""
1840 ?=" | | | |"
1850 #=I=4*R
1855 I=I-6
1860 ?=" -----+-----+-----" 1870 #=1720
1880 ?=" !!!YOU WIN!!!"
1890 H=H+1
1900 #=1970
1910 #=1650
1920 ?=" YOU LOSE."
1930 J=J+1
1940 #=1970
1950 ?=" CAT GOT THIS ONE."

Page 33 of 36

1960 Q=Q+1
1970 $=13
1975 ?=" PLAY AGAIN? ";
1977 $=8
1980 S=$
1990 #=S=89+(S=121)=0*2020 2000 #=S=89*2006
2002 ?="es"
2004 #=1030
2006 ?="ES"
2010 #=1030
2020 #=S=78+(S=110)=0*1970 2030 #=S=78*2036
2032 ?="o"
2034 #=2040
2036 ?="O"
2040 ?=""
2050 ?=" | I WON ";
2060 ?=J
2070 ?=" GAME";
2072 #=J=1*2076
2074 ?="S";
2076 ?=""
2080 ?=" YOU WON ";
2090 ?=H
2100 ?=" GAME";
2102 #=H=1*2106
2104 ?="S";
2106 ?=""
2110 ?=" WE TIED ";
2120 ?=Q
2130 ?=" GAME";
2132 #=Q=1*2136
2134 ?="S";
2136 ?=""
2137 ?="HIT ANY KEY TO EXIT"
2138 Z=$
2140 *=0

Note-1: Those last 3 lines are *only* used on compiled programs to make it exit to DOS. You don’t need to include them on terminal-based programs.

Note-2: This particular program requires SLIGHTLY *OVER* 2K of memory to run. It could be (and has been in the past) trimmed down to just barely run with 2048 bytes on the 680B; but I no longer have a copy of that version.

Using single-character home-up and clear-screen gets most of the needed space; but not quite enough. Some serious editing would have to be done to save the needed space.

It’s included as an example for those with more memory or using the compiled version of VTL-2.

Page 34 of 36

RENUMBER

680B version | 8800 version | Compiled version

64000 A=#
64010 C=#
64020 B=&
64030 &=B
64040 ?="STARTING #? ";
64050 D=?
64060 ?="STEP SIZE? ";
64070 E=?
64080 &=1
64090 G=131 | 64090 G=159 | 64090 G=0-1
64100 J=0
64110 I=&
64120 H=#+1
64130 &=I
64140 G=&+1/2+G
64150 &=%
64160 #=:G)>A*15*(C-A)+#
64170 #=D-1>(A-1)+(J>D)>1*C 64180 :G)=D
64190 &=&+1
64200 J=D
64210 D=D+E
64220 I=&
64230 &=B
64240 K=#+1
64250 &=I+1
64260 X=:G)/256*0+%
64270 I=&
64280 &=B
64290 #=%>1*K
64300 #=H
64310 ?="DONE"
64320 ?="TO REMOVE RENUMBER FROM PROGRAM, TYPE: &="; 64330 ?=G*2+&
64340 ?=""
64350 &=B

Note-1: The only difference between the three variations is line number 64090; which is half the size of & minus-one, on an empty program.
Note-2: The program itself is relocatable. I.e., it, itself can be renumbered and it will still run. However, the step-size between program steps must remain constant in the source, or line 64160 will not work right. Also, the largest number of the program to be renumbered must be less than the first number of the renumber program itself. That’s why the numbers are large.
Note-3: This version of the renumbering program ONLY renumbers the basic line-numbers, not computed goto statements. Therefore a renumbered program will have to be edited manually to make all the “gotos” match the original source.
Note-4: To renumber a program, simply type-in or load RENUMBER.VTL on top of an existing program, type: #=64000and let it run.

Page 35 of 36

(Blank – The End...)

Page 36 of 36

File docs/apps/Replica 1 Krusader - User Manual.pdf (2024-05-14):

# User Manual for

# KRUSADER

Ken’s Rather Useless Symbolic Assembly Development Environment for the Replica 1 or is that Reasonably Useful? You decide!

### Ken Wessen

ken.wessen@gmail.com

### Version 1.1 – July 28, 2006

## 1 Introduction

KRUSADER is a program written to allow assembly language development on the Replica 1 – an Apple 1 clone designed by Vince Briel¹
, and described in the book Apple 1 Replica Creation: Back to the Garage by Tom Owad²
. KRUSADER includes a simple shell and editor, a single-pass symbolic assembler, and a disassembler, and fits in just under 4K (so it is small enough to fit in the 8K of Replica 1 ROM along with the monitor and Apple BASIC). Although designed for the Replica 1/Apple 1, there is very little system dependent code, and since full source code is provided, KRUSADER can easily be adapted to any other 6502 based system. However, it’s limitations may mean it is not an appropriate tool in many cases (for example, it has no concept of a file-system and so would not be particularly suitable for use on an Apple II).
KRUSADER handles a fairly standard and expressive syntax for its assembly source code. For users who are unfamiliar with the 6502 instruction set, I recommend the introduction by Andrew John Jacobs that can be found at http://www.obelisk.demon.co.uk/6502/. On a Replica 1, KRUSADER can assemble over 200 lines of code per second, and given its 32K of RAM, the defaults provide space for around 20K of tokenised source code, 7K of generated code, and up to 256 global symbols.
KRUSADER is distributed as two binaries – one to be loaded in high RAM at addresses $7100-$7FFF, and the other that belongs in ROM from $F000-$FEFF. Source is also provided, so alternative binaries are easy to produce. I use the 6502 simulator by Michal Kowalski³
to assemble

1http://www.brielcomputers.com
2http://www.applefritter.com/replica
3http://home.pacbell.net/michal k/ (http://home.pacbell.net/michal_k/)

the object code, and test it on the Pom1 simulator⁴ and my Replica 1. Addresses quoted in this manual will be for the high RAM version of the code, with the ROM version values following in brackets, but these values are easily offset for a version with any particular starting address.

## 2 Sample Session

The best way to give a quick overview of the system and its operation is to work through a couple of simple examples. First thing is to load the program, and once loaded run it by typing 7100R(F000R). At this point you will be presented with a brief message showing the version of the assembler you are running, followed by the shell prompt ? . Type N to enter a new program, and enter the code shown below. The column layout is important, with the source organised in fields. After the current line number is printed by the editor, the next 6 characters are the label field, then after a space there is the 3 character mnemonic field, then after a space a 14 character arguments field, and finally a comments field of maximum 10 characters. Hitting tab or space will automatically progress you to the next field, and to finish entering code, hit the escape key (hit return first though, or you will lose the current line). If you make an error typing a line, hitting backspace will return you to the start of the line (there is no true backspace on the Apple 1, and I have chosen not to implement the underscore-as-backspace hack used in the Apple 1 monitor and Apple 1 BASIC since it confuses the syntactically important column layout). If you only notice an error after hitting return and need to change a line, type E nnn, where nnn is the line number in question (it is not necessary to enter any leading zeroes). If you missed a line out altogether, type I nnn to insert at line nnn.

? N
000 | LDA #’A’
001 LOOP | JSR $FFEF
002 | CLC
003 | ADC #$1
004 | CMP #’Z’+1
005 | BNE LOOP
006 | RTS
007<esc>

When you have finished entering the source, type L to list the code, and then A to assemble it. You should see the assembler output 0300-030C, indicating the target memory locations used by the assembled code. Any errors detected in the code will be displayed at this point, and can be fixed using either the I and E commands described above, or the X nnn mmm command for deleting a range of lines (the second argument mmm is optional). Once the code has been successfully assembled, run it by typing R $300. The program will run and output the string

ABCDEFGHIJKLMNOPQRSTUVWXYZ

4The original is at http://www.chez.com/apple1/Apple1project/, and a bug-fixed version is at http://school.anhb.uwa.edu.au/personalpages/kwessen/apple1 and then return to the shell (because of the final RTS).
In order to illustrate some more advanced features of the assembler, a second, more complicated example is the following.
000 ECHO | .= | $FFEF
001 START | .= | ’A’
002 END | .= | ’Z’
003 STEP | .= | $30
004
005 SETUP | .M | $280
006 | LDA #$1
007 | STA STEP
008 | LDA #START
009 | RTS
00A
00B FWD | .M | $300
00C .LOOP | JSR ECHO
00D | CLC
00E | ADC STEP
00F | CMP #END
010 | BMI .LOOP
011 | RTS
012
013 BACK | .M | $320
014 .LOOP | JSR ECHO
015 | SEC
016 | SBC STEP
017 | CMP #START
018 | BPL .LOOP
019 | RTS
01A
01B MAIN | .M | $340
01C | JSR SETUP
01D | JSR FWD
01E | JSR BACK
01F | RTS

Again, type L to list the code. Since this program is longer than 24 lines (i.e. one Apple 1 screen), the listing will pause after 22 lines and wait for a keypress. Hitting return will move the listing forward by one line, escape will cancel the listing, and any other key will list the next 22 lines. Typing A will assemble the code – this time made up of 4 modules, each with their own starting address. The assembler will output the following upon successful assembly:

? A
0300-02FF
SETUP | 005 0280-0286
FWD | 00B 0300-030A
BACK | 013 0320-032A
MAIN | 01B 0340-0349
?

This output shows the first source line number and the memory locations used by each module in the source code (the first line can be ignored because no code is generated prior to the declaration of the SETUP module). Hitting M will show the memory taken up by the source code, in this case 2000-20E5(2300-23E5), and the value of global symbols can be queried by using the V command – e.g. typing V MAIN will get the response 0340. This is important, because it is the entry point for this program, and running it by typing either R $340 or R MAIN will result in the output:

ABCDEFGHIJKLMNOPQRSTUVWXYZYXWVUTSRQPONML
KJIHGFEDCBA

Some other relevant features of this second example are the use of blank lines for layout, and symbols to represent both constants (e.g. START .= ’A’) and memory locations (e.g. STEP .= $30). Also note the use of the local label .LOOP in both the FWD and BACK modules. Local labels are indicated by an initial ’.’, and have module level scope only. The .= and .M commands are two directives recognised by the assembler for defining symbols and modules respectively. It is not necessary to give a memory location argument to the .M directive, and indeed only in very special circumstances would you wish to do so.

## 3 Shell Commands

The previous section introduced most of the available shell commands, in the context of a sample interactive session. Shell commands are entered in response to the ? prompt, and are all single key commands, with between zero and two arguments. If the shell cannot process an entered command, ERR: SYN is output to indicate a syntax error. Five of the twelve shell commands are for source editing, and the others are for assembling, running, disassembling, querying symbols and source memory, entering the monitor, and recovery. Table 1 gives a summary of all commands and their syntax.

## 4 Source Code

As described in section 2, source code in KRUSADER requires strict adherence to a specific column-based format. The editor both assists and enforces source code entry to match this format by auto-forwarding on a space and ignoring invalid keypresses. In addition, any non-blank line must have either a valid mnemonic or directive, or start with the comment character (;). The sections below describe the source format and the legal entries for each field in detail.

Command | Arguments | Action
N | | Start a new program. This command will clear any ex- isting source, and prompt for source entry from line 000.
I | <nnn> | Insert code from line nnn, or at the end if no argument. If k lines are inserted, existing lines from nnn are shifted down by k.
L | <nnn> | List the source starting from line nnn, or the beginning if no argument. The listing pauses for input every page – hitting return shows the next line, escape cancels the listing, and any other key shows the next page.
X | nnn <mmm> | Delete from lines nnn to mmm inclusive. If just one argument, delete line nnn only. Care must be taken since this will change the line number associated with all subsequent source lines. Delete cannot be undone.
E | nnn | Edit line nnn, and insert after. This is equivalent to typ- ing X nnn followed by I nnn, so the existing line is deleted immediately, and as for the X command, it cannot be recovered.
M | | Show the memory range used to store the current source code.
A | | Assemble the current source code.
V | LABEL | Show the value of the given label.
R | $nnnn or LABEL | Run from address $nnnn. If the program ends with an RTS, control is returned to the shell. Otherwise, re-enter the shell at address $711A($F01A).
D | <$nnnn or LABEL> | Disassemble 20 instructions from address $nnnn, or con- tinue from the last address if no argument.
$ | | Drop into the Apple 1 Monitor. You can re-enter the shell at address $711A($F01A).
P | <c> | Panic! This command attempts to recover lost source (usually due to zero page data corruption). If the 1st line of source starts with a label, then give the first letter of that label as an argument to this command. For more detail, see the section on source tokenisation 6.2

Table 1: KRUSADER shell commands. Optional arguments are indicated by < · · · >.

### 4.1 Labels

Labels are up to 6 alphanumeric characters in length, and may be either global or local in scope. Local labels are defined for the current module only, whereas global labels are accessible anywhere in the program. Up to 256 global labels may be defined, and up to 32 local labels in any one module. Local labels are any labels that begin with a . (i.e. a period).
Labels may be used prior to being defined, i.e. as forward references, and up to 85 forward references are allowed. However, forward references are more limited than normal labels since they are always treated as words (i.e. 2 bytes in size), and any expression involving them must also result in a 2 byte value. In particular this means forward references cannot be used with the < and > operators (see section 4.5).
Once any particular module has been assembled, all local labels are cleared and an error is reported if any forward references involving local labels remain unresolved. However, any forward references to global labels that remain unresolved are simply held, and will only cause an error if they are still unresolved once assembly of the entire program has been completed.
KRUSADER will report an error if a global label is redefined, or a local label is redefined within a module.

### 4.2 Mnemonics

KRUSADER recognises the standard 3 character mnemonics for all legal 6502 instructions only. These are shown in table 2. Undocumented opcodes and 65C02 opcodes are not supported, and the editor will not accept any line with an invalid entry in the mnemonic field. Note that although when the 6502 executes a BRK instruction, the return address pushed onto the stack is PC+2, KRUSADER assembles the BRK opcode as a single byte. The .B directive (see section 4.6 below) should be used to set the value of any desired padding byte.

Operations | Mnemonics
Load/Store | LDA, LDX, LDY, STA, STX, STY
Transfer | TAX, TXA, TAY, TYA, TSX, TXS
Stack | PHA, PLA, PHP, PLP
Logical | AND, EOR, ORA, BIT
Arithmetic | ADC, SBC, CMP, CPX, CPY
Increment/Decrement | INC, INX, INY, DEC, DEX, DEY
Shift | ASL, LSR, ROL, ROR
Jump/Call | JMP, JSR, RTS
Branch | BCC, BCS, BEQ, BNE, BMI, BPL, BVC, BVS
Status Flag | CLC, CLD, CLI, CLV, SEC, SED, SEV
Other | BRK, NOP, RTI

Table 2: Recognised mnenomics.

### 4.3 Arguments

Table 3 shows the argument format for each of the 6502’s addressing modes. In addition, $nnnn can always be replaced by a label or expression, and similarly $nn so long as the result is a single byte. (Expressions are introduced in section 4.5 below.) A single byte may also be represented using ’c’ for a given printable character when immediate mode is being used. Whenever a word sized argument actually has a high byte of zero and the corresponding byte size addressing mode is legal, the byte size mode will be used. In addition, some mnemonics support the absolute,Y addressing mode but not the zero page,Y mode. In these cases, a byte sized argument will be increased to word size in order to make the instruction legal. Constants are always expressed using hexadecimal notation.

Addressing Mode | Format | Addressing Mode | Format
Implicit | | Absolute | $nnnn
Accumulator | | Absolute,X | $nnnn,X
Immediate | #$nn or #’c’ | Absolute,Y | $nnnn,Y
Zero Page | $nn | Indirect | ($nnnn)
Zero Page,X | $nn,X | Indexed Indirect | ($nn,X)
Zero Page,Y | $nn,Y | Indirect Indexed | ($nn),Y
Relative | *+/-nn

Table 3: Source code syntax for the 13 addressing modes of the 6502.

### 4.4 Comments

There are two ways to include comments in KRUSADER source. Full line comments may be entered by typing a ’;’ character as the first character in the line, followed by a space⁵
. Then
all line space from the mnemonic field onwards can be used for comment text. Alternatively, the remainder of any line after the end of the argument field is also reserved for comments, and in this case, no special character is required to preceed their entry.
Comment entry is the only place where spaces are treated literally, and examples of both kinds of comments are shown in the code snippet below:
003 ; | HERE IS A LONG COMMENT
004 | CMP #’Z’+1 | HERE IS
005 | BNE LOOP | A SHORT
006 | RTS | ONE

5Strictly speaking the space is not required, but if it is absent, the source formatting will be upset.

### 4.5 Expressions

KRUSADER allows the use of 4 operators when a label is used in a mnemonic’s argument: +, -, < and > for plus, minus, low byte and high byte respectively. The plus and minus operators take a constant signed byte argument only, and unlike other places where constants are employed, the argument requires no preceeding $. The high and low byte operators are used to extract the relevant single byte from a word sized constant or label, and have lower precedence than + and -, and so are applied last of all when evaluating the expression.
For example, if we define the symbols BYTE .= $12 and WORD .= $3456, then the following expressions are evaluated as listed below:
- BYTE+1 | = $13, | • WORD+FF | = $3455,
- BYTE+80 | = $FF92, | • >WORD | = $34,
- <BYTE+80 = $92, | • <WORD | = $56,
- WORD+1 | = $3457, | • >WORD+10 = $34,
- WORD-1 | = $3455, | • <WORD+10 = $66.

As described in section 4.1, forward references can be used in expressions involving the + and
- operators, but not in expressions involving the < and > operators.

### 4.6 Directives

In addition to the 6502 mnemonics described in section 4.2, KRUSADER supports a number of directives for managing symbolic constants, program structure and data. Directives are entered in the mnemonic field, and always consist of a period followed by a single letter. Each of the available directives is described in table 4 below.

Directive | Action
LABEL .= $nnnn LABEL .M <$nnnn> <LABEL> .B $nn <LABEL> .W $nnnn <LABEL> .S ’cc. . .c’ | Define a named constant. The label must be global in scope, and expressions or a quoted character are allowed. Define a new module. If no address is specified, the code continues on from the previous module. The label must be global in scope, and expressions are not allowed. Store the byte-sized value $nn at the current PC. Ex-pressions or a quoted character are allowed. Store the word-sized value $nnnn at the current PC in little-endian byte order. Expressions are allowed. Store the string literal at the current PC. The string must be 13 characters or less, and contain no spaces.

Table 4: Directives supported by KRUSADER . Optional fields are indicated by < · · · >. Forward references are never allowed in argument expressions.

## 5 Errors

Error reporting in KRUSADER is necessarily limited by its size constraints, but nevertheless it attempts to capture as many errors and ambiguities as possible, and report them in a meaningful way. Errors can arise in response to a shell command or as a result of an assembly. When appropriate, the offending line or symbol will be displayed.

Error | Meaning
ERR: SYN | Syntax error in either a shell command or a source code line.
ERR: MNE | An illegal mnemonic code was encountered.
ERR: ADD | An illegal addressing mode was encountered.
ERR: SYM | A needed symbol was not found.
ERR: OVF | Too many symbols has lead to a symbol table overflow.
ERR: UNK | An unknown error has occurred. This should never be seen!

Table 5: KRUSADER error messages.

There are many reasons why an “ERR: ADD” may occur, especially if the offending line involves symbols. For this reason it can be helpful to query the symbols involved using the V command (see table 1). If the symbol is indeed the cause of the addressing mode error, the V command will report a more useful error, such as “ERR: SYM” if the symbol is undefined, or “ERR: OVF” if the symbol tables are full.

## 6 Low Level Information

This section is concerned with some of the low-level information about how KRUSADER works, and is not required for normal use of the assembler. However, there are many situations where this information is quite important for managing source and machine code, and correcting errors.

### 6.1 Memory Map

Proper operation of the assembler requires a number of things to reside in the machine’s memory. There is the assembler code itself, the program source code, the assembled code, and various symbol tables. The default arrangement for both the high RAM and the ROM versions of KRUSADER are shown in figure 1. The local symbol and forward reference tables take up a fixed 1K of space, with 256 bytes taken up by the locals, and the remainder for the forward references. The global symbol table grows downward to a maximum of 2K (corresponding to 256 symbols). The two most important source locations have both been mentioned already, and are $7100($F000) for initial program entry, and $711A($F01A) for returning to the shell.
KRUSADER also uses a number of zero page locations, but mostly as an input buffer and during assembly. The only locations that must be maintained are $F8, $F9, $FE and $FF. These hold the high byte of the default assembled code storage location, the high byte of the local/global symbol

KRUSADER code

Forward References
Local Symbols

Global Symbols

Program Source

Program Target

Zero Page

FEFF

F000

7D00
7C00

7400

2000

0300
0100
0000

7FFF

7100

6E00
6D00

6500

1D00

0300
0100
0000
70FF | 7FFF
High RAM Version | ROM Version

Figure 1: Memory map for both the high RAM and the ROM versions of KRUSADER . Note that the global symbol table starts at the local/global table boundary and grows downwards, whereas the program source starts at the low address and grows upwards. As mentioned in section 6.1, the important values are the high byte of the target memory, the high byte of the local/global symbol table boundary, and the start of the source code storage. For the RAM version, the values are $03, $6D, $00 and $1D, and for the ROM version they are $03, $7C, $00 and $20. After initialisation, these values are stored in zero page locations $F8, $F9, $FE and $FF.

table boundary, and the low and high bytes of the source code storage location respectively (See figure 1 for the appropriate values). Replica 1 users need to beware of BASIC because it may overwrite these four values, so they need to be restored before returning to the KRUSADER shell⁶ .

### 6.1.1 Changing Default Memory Locations

The default values for the RAM based version of KRUSADER can be altered by changing the values at memory locations $7101, $7105 and $7109 in the assembler code. For the ROM based version, the default values can only be altered after the program has been run, and the alternative values must be entered directly into the zero page locations mentioned above, before resuming KRUSADER at location $F01A⁷

6The P command is useful for restoring the default values to these zero page memory locations.
7The P command will overwrite any values entered in this way.

### 6.2 Source Tokenisation Scheme

Any entered source is stored in a tokenised form in order to save space. The tokenisation employed is quite simple because there was even less space available in the code to implement it! Three special codes are employed – $01 as a field terminator, $00 as a line terminator, and $02 00 to indicate a blank line. Labels, arguments and comments are stored as entered with the field terminator marking their end, and mnemonics and directives are encoded as a single byte. Program end is indicated by a line starting with $00. This simple scheme results in a reduction of the source code size by a factor of 2 to 3.
Also provided in the KRUSADER distribution is C source code for a program that can convert more general source code formats to the required tokenised form, so that they may be uploaded to the assembler. However, this simple program does not translate different formats for directives or addressing mode specification, so if any such changes are required, they must be done manually. Once you have the converted source data, simply launch KRUSADER as normal, enter the monitor and load in the tokenised data to the source storage memory, and resume. The source will then be available to KRUSADER as if you had typed it in as normal. However, syntax and formatting errors in the source may not be well handled since the error handling is designed around the restrictions placed on source input in the usual manner.
One useful thing to keep in mind is the N command simply clears the source program from memory by putting a $00 as the very first byte of the source storage location. So if N is typed accidentally, the source can be easily restored. To do this manually, simply enter the monitor using $, and change this initial byte to either $01 if there was no label, or the first byte of the label, and then resume KRUSADER as normal with 711AR(F01AR). This process is automated by the P command. You should note however that there is no way to recover source lines deleted with the X or E commands since the memory is immediately overwritten.

### 6.3 Moving Memory

If you want to copy a block of memory to another location (if you are backing up source or machine code via the expansion interface for example), you can make use of one of the memory moving subroutines inside the assembler as follows. First work out non-overlapping source and destination addresses – call these srcL, srcH, destL and destH, and then the size of memory to move – sizeL and sizeH. (You can do this using the M command for source or watching the output of the A command for assembled code.) Then drop into the monitor using the $ command, and enter: 50: srcL srcH destL destH sizeL sizeH to set the parameters, and 7338R (F238R) to do the move.

### 6.4 Testing

KRUSADER comes with a number of sample programs, both in binary and hex dump formats, and these are useful for verifying its correct operation. The most important sample in this regard is TestSuite.asm, which contains a number of modules for testing the assembler. The first test of course is that the source assembles without error, then R MAIN will cause the program to verify its own assembled code and report any errors. This test suite covers all the 6502 instructions, using all their addressing modes and a couple of different formats for arguments where relevant, as well as each of the available directives. In addition, both forward referencing and the various kinds of expressions supported by KRUSADER are tested – both alone and in combination with various addressing modes. A successful run of this suite of tests is a very good indication that KRUSADER is functioning properly.
Because of the size of the test suite code, it can not be run with the RAM version of KRU-SADER without changing the start address for program source storage as described in section 6.1.1 in order to allow enough room for the source code, the assembled code, and the global symbol table. Specifically, prior to running KRUSADER , the value at address $7105 needs to be changed to $14, or if KRUSADER is already running, this value of $14 can be loaded directly into the zero page address $FF. The source code data can then be loaded from address $1400 onwards, and then assembled and run as normal.

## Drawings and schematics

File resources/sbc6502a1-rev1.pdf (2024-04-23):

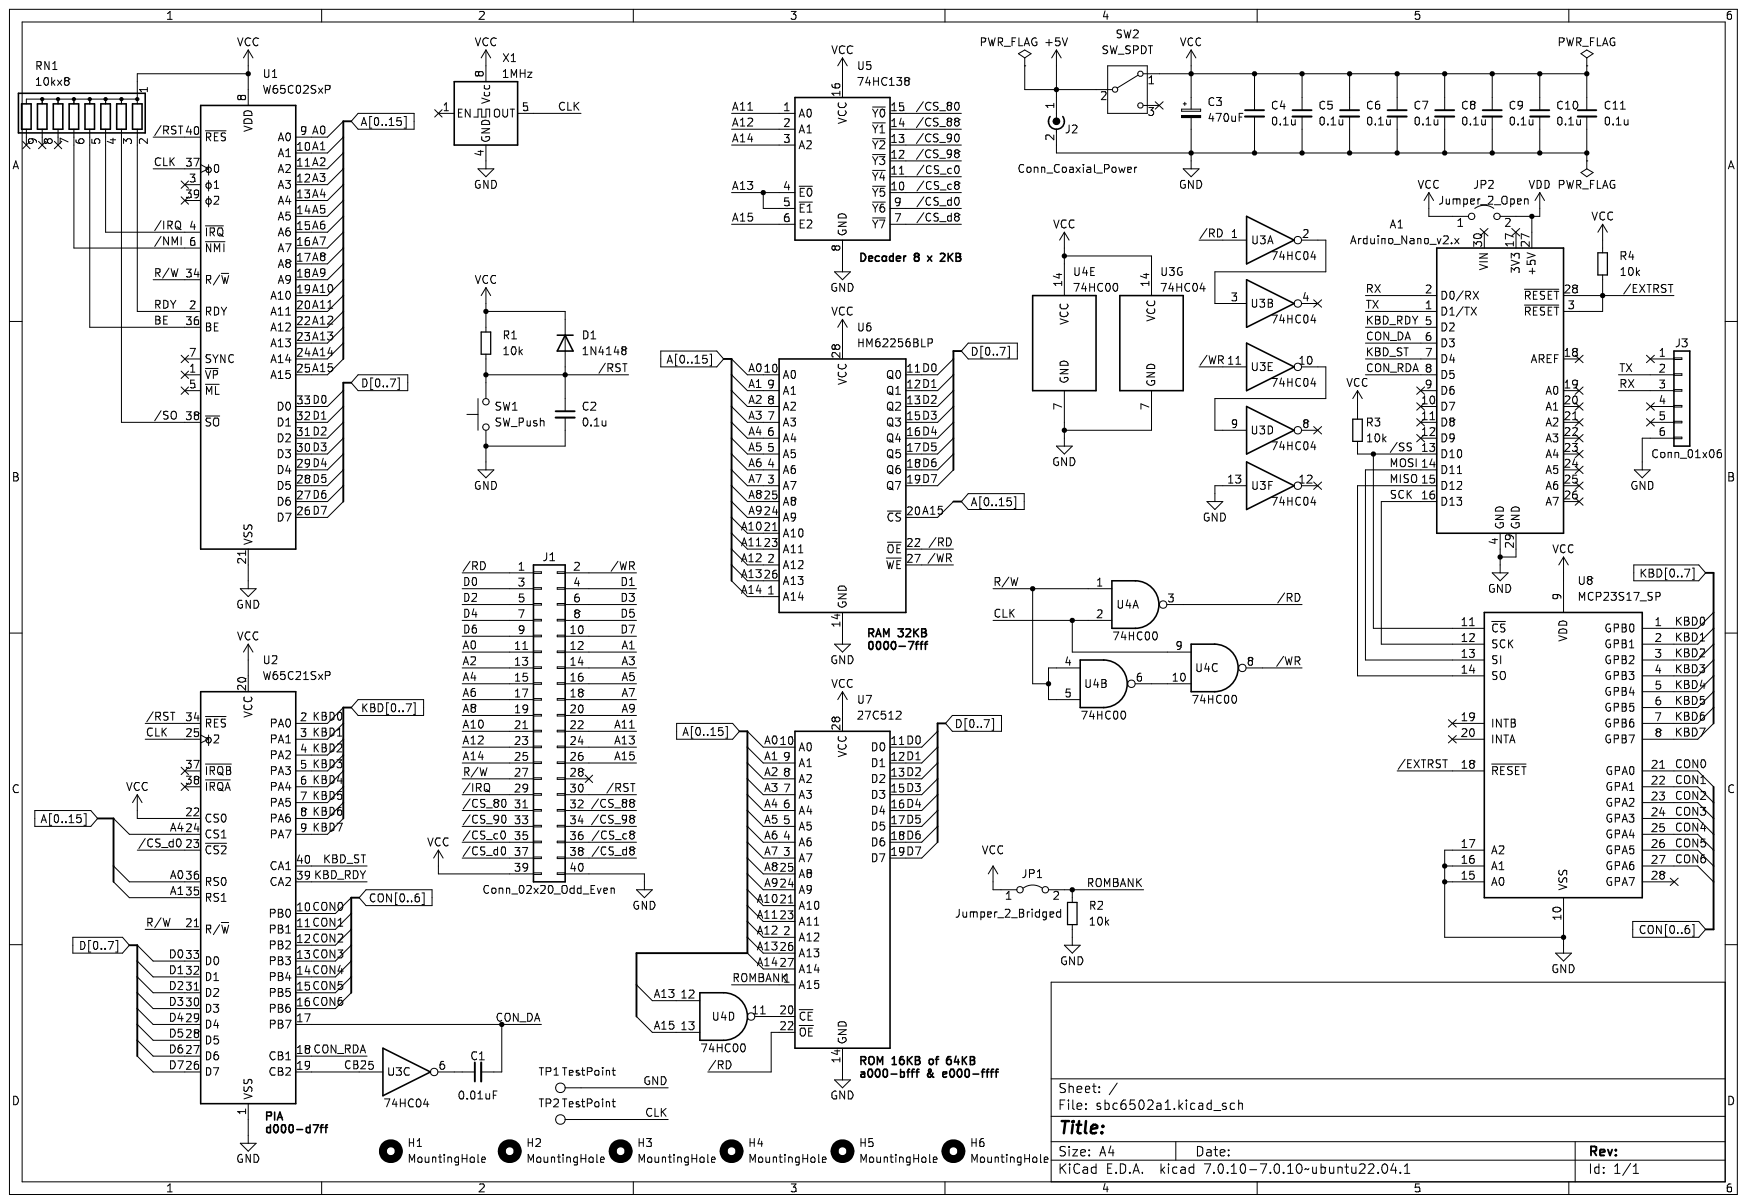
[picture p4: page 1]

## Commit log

2024-04-23 PCB rev.1
    [sbc6502a1-B_Cu.gbl, sbc6502a1-B_Mask.gbs, sbc6502a1-B_Silkscreen.gbo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]
2024-05-09 fix firmware
    - fix ROM image
    - drop tinybasic
    - import a1-assembler
2024-05-10 add apps
    [applesoft.cfg, cbmbasic1.cfg, cbmbasic2.cfg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]
